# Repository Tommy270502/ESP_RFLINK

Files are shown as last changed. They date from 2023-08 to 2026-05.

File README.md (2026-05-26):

# Wireless Dev Bridge

Wireless Dev Bridge is a USB-C developer kit for ESP32-S3 and nRF24L01+ work. It gives one bench dongle a shared JSON command protocol over USB serial, HTTP, WebSocket, and BLE, plus a Python SDK, CLI, local web workbench, firmware browser dashboard, KiCad hardware source, and manufacturing outputs.

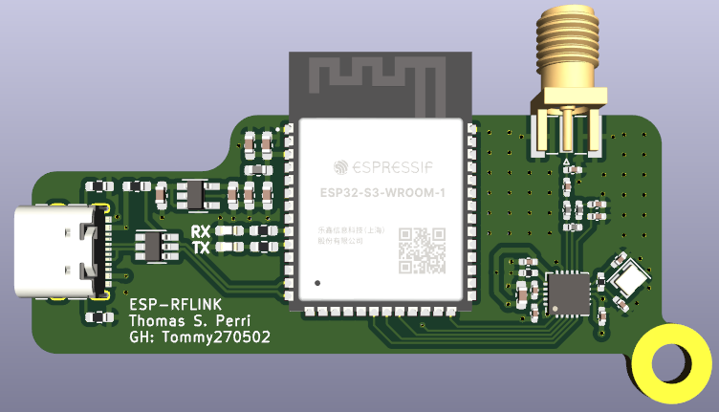
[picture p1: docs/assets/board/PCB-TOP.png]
Wireless Dev Bridge PCB top view


## Start Here

1. Read [Getting Started](docs/getting-started.md) for firmware build, SDK install, and first RF validation.
2. Use the local web workbench:

   ```bash
   pip install -r application/requirements.txt
   python application/main.py
   ```

3. Or install the SDK and CLI:

   ```bash
   cd sdk/python
   python -m pip install -e ".[all]"
   wdb discover
   wdb --serial COM5 identify
   wdb --serial COM5 diagnostics
   ```

4. For a two-dongle kit, flash one `node1` and one `node2`, then run:

   ```bash
   wdb pair-test --node1-serial COM5 --node2-serial COM6
   ```

## Product Surfaces

| Surface | Location | Description |
| --- | --- | --- |
| Firmware | `Firmware/ESP32_RFLINK` | PlatformIO ESP32-S3 firmware. |
| Local web workbench | `application` | FastAPI/browser host tool at `http://127.0.0.1:5173`. |
| SDK/CLI | `sdk/python` | Python SDK, CLI, examples, and hardware-free tests. |
| Firmware browser dashboard | `http://192.168.4.1` | Served by the dongle SoftAP. |
| Hardware | `hardware/kicad` | KiCad schematic and PCB source. |
| Manufacturing | `manufacturing/gerbers` | Current V1 Gerber/drill export. |

All transports share one command response envelope:

```json
{"ok":true,"cmd":"status","data":{},"error":null}
```

See [Project Overview](project-overview.md) for interfaces, validated bench workflows, and architecture detail.

## Protocol 1.1 Capabilities

- Shared command envelope over USB serial, HTTP, WebSocket, and BLE.
- Runtime RF config, address management, send/listen/flush, and bridge toggles.
- Settings persistence through NVS with `settings_get`, `settings_set`, `settings_save`, and `settings_reset`.
- Diagnostics and identify commands for support and physical device matching.
- Optional token auth for HTTP, WebSocket, and BLE command surfaces.
- Support report export from the CLI and local web workbench.

## Development Checks

```bash
cd Firmware/ESP32_RFLINK
pio run -e node1 -e node2

cd ../../sdk/python
python -m pytest

cd ../..
python -m py_compile application/main.py
python scripts/check_docs_links.py
```

## Documentation

- [Documentation Index](docs/documentation-index.md)
- [Project Overview](project-overview.md)
- [Getting Started](docs/getting-started.md)
- [First Run](docs/first-run.md)
- [API Reference](docs/api-reference.md)
- [Firmware Guide](docs/firmware.md)
- [Hardware Guide](docs/hardware.md)
- [Security Model](docs/security-model.md)
- [Troubleshooting](docs/troubleshooting.md)
- [Release Checklist](docs/release-checklist.md)
- [Local Web Workbench](application/desktop-workbench.md)
- [Python SDK](sdk/python/python-sdk-guide.md)

## V1 Boundaries

- nRF24 payloads are limited to 32 bytes.
- nRF24 address width is fixed at 5 bytes.
- RF configuration is runtime-only until saved with protocol 1.1 settings commands.
- HTTP, WebSocket, and BLE APIs are intended for trusted developer/lab networks.
- OTA, cloud connectivity, packet decoding, persistence, and mesh networking are out of scope for V1.

## License

Software is licensed under the MIT License; see [LICENSE](LICENSE). Hardware source and manufacturing outputs use the hardware license notice in [hardware/LICENSE.md](hardware/LICENSE.md).

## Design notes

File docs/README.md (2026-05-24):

# Documentation

Project documentation for Wireless Dev Bridge V1.

Start here:

- [Getting Started](getting-started.md): clone-to-hardware workflow.
- [API Reference](api-reference.md): shared JSON command protocol, HTTP routes, WebSocket events, and BLE UUIDs.
- [Firmware Guide](firmware.md): PlatformIO environments, modules, pin map, runtime defaults, and command examples.
- [Hardware Guide](hardware.md): KiCad source, board assets, manufacturing review notes, and firmware pin alignment.
- [Release Checklist](release-checklist.md): pre-release checks across firmware, host tools, RF validation, hardware, security, and support.

Host tool documentation lives with the tool:

- [Local Web Workbench](../application/README.md)
- [Python SDK](../sdk/python/README.md)

Validated V1 workflows:

- Two-dongle nRF24 ACK traffic over USB serial control.
- Runtime RF configuration from the local web workbench, CLI, SDK, HTTP, WebSocket, or BLE.
- Live packet monitoring through WebSocket and BLE notifications.
- Wi-Fi AP station count, BLE connection state, and RF TX/RX counters through `status`.

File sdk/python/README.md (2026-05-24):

# Wireless Dev Bridge Python SDK

Host-side SDK for the Wireless Dev Bridge firmware.

## Install

HTTP-only usage has no runtime dependencies:

```bash
# from the repository root
cd sdk/python
python -m pip install -e .
```

Install transport extras for USB serial, WebSocket, BLE, and MQTT examples:

```bash
python -m pip install -e ".[all]"
```

For tests only:

```bash
python -m pip install -e ".[test]"
```

## Quick Start

Minimal Wi-Fi connection, when your computer is connected to the dongle AP:

```python
from wireless_dev_bridge import BridgeError, WirelessDevBridge

dev = WirelessDevBridge.http("192.168.4.1", timeout=3.0)
try:
    print(dev.status())
    print(dev.rf_send_hex("1234", require_ack=False))
except BridgeError as exc:
    print(f"device request failed: {exc}")
finally:
    dev.close()
```

USB serial:

```python
from wireless_dev_bridge import WirelessDevBridge

dev = WirelessDevBridge.serial("COM5")
try:
    print(dev.self_test())
    dev.rf_send_bytes(b"hello", require_ack=True)
finally:
    dev.close()
```

BLE:

```python
from wireless_dev_bridge import WirelessDevBridge

dev = WirelessDevBridge.ble("WirelessDev-Node1")
try:
    dev.bridge(rf_to_ble=True)
    print(dev.protocol())
finally:
    dev.close()
```

## Getting Started By Workflow

Monitor RF packets from a dongle.
Use this when you need a live packet log during firmware bring-up or RF troubleshooting.

```bash
python examples/packet_monitor.py --ws 192.168.4.1 --count 10
python examples/packet_monitor.py --ble WirelessDev-Node1 --count 10
```

Expected output shape:

```text
2026-05-05T12:00:00+00:00 uptime_ms=12345 len=2 hex=1234
```

Bridge RF events to BLE.
Use this when a BLE host, phone app, or field tool should receive nRF24 packet events from the dongle.

```bash
wdb --ble WirelessDev-Node1 bridge rf-to-ble on
python examples/packet_monitor.py --ble WirelessDev-Node1 --count 10
```

Expected command response shape:

```json
{"ok":true,"cmd":"bridge","data":{"rf_to_ble":true},"error":null}
```

Bridge RF events to MQTT.
Use this for test benches, lab automation, or dashboards that already consume MQTT.

```bash
python -m pip install -e ".[mqtt]"
python examples/bridge_to_mqtt.py --ws 192.168.4.1 --broker localhost --topic-prefix lab/bridge1
```

Expected MQTT payload shape:

```json
{"type":"packet","source":"rf","data":{"len":2,"hex":"1234","uptime_ms":12345}}
```

Run a bench inventory/self-test.
Use this before a test run to verify firmware version, role, heap, radio health, and RF config.

```bash
python examples/device_inventory.py --device serial:COM5 --device serial:COM6
```

Expected output shape:

```text
SPEC                     OK  ROLE     FW         BLE                RADIO CH  RATE    RX       TX
serial:COM5              yes node1    0.1.0-v1   WirelessDev-Node1  yes   76  1mbps   NODE1    NODE2
```

Measure transport latency.
Use this to compare HTTP, USB serial, WebSocket, and BLE command round trips.

```bash
python examples/latency_benchmark.py --host 192.168.4.1 --count 50
python examples/latency_benchmark.py --ble WirelessDev-Node1 --count 50 --json
```

Expected output shape:

```text
http 192.168.4.1 ping
count=50 min=12.20ms avg=18.40ms p95=28.10ms max=31.80ms
```

Use the CLI for quick validation.
Use this when you want a fast smoke check without writing Python code.

```bash
wdb --serial COM5 self-test
wdb --host 192.168.4.1 status
wdb --ws 192.168.4.1 bridge rf-to-wifi on
wdb --ble WirelessDev-Node1 bridge rf-to-ble on
```

## Production Test

Run the bundled two-device production test over USB serial:

```bash
python examples/rf_ping.py --node1-serial COM8 --node2-serial COM11
```

This script:

- verifies each device role and radio health
- sets complementary RF addresses
- applies a known RF config
- flushes FIFOs and enables listening
- sends an ACK-required payload in each direction
- confirms the opposite device received the expected RF packet

For network-driven tests, pass the reachable HTTP host for each dongle. A dongle in SoftAP mode normally serves HTTP at `192.168.4.1`; if you are testing two SoftAP dongles, your host must connect to the correct AP or provide separate reachable routes for each device. USB serial is the simplest two-node path:

```bash
python examples/rf_ping.py --node1-serial COM8 --node2-serial COM11
```

## Examples

- `examples/packet_monitor.py`: stream RF packet events over WebSocket, BLE, or serial.
- `examples/bridge_to_mqtt.py`: publish RF packet events to MQTT. Requires `paho-mqtt` or `.[mqtt]`.
- `examples/ble_console.py`: run interactive or one-shot maintenance commands over BLE.
- `examples/latency_benchmark.py`: measure command or optional RF send latency.
- `examples/device_inventory.py`: run `self_test` and RF config reads across multiple devices.
- `examples/rf_ping.py`: two-device RF production test.
- `examples/production_demo.py`: flash two USB dongles, run two-way RF validation, and write a demo/factory JSON report.

All examples support `--help`.

## Two-Dongle Production Demo

Use this when presenting or validating a packaged two-dongle kit.

List connected serial ports:

```bash
python examples/production_demo.py --list-ports
```

Build, flash, test, and write a report:

```bash
python examples/production_demo.py --node1-serial COM5 --node2-serial COM6 --flash --operator TP --lot EVT1
```

If exactly two serial ports are visible and you want the script to choose them:

```bash
python examples/production_demo.py --auto-ports --flash
```

The report is written to `reports/` by default and includes role validation, radio health, RF config, ACK send checks, receive confirmation, elapsed time, and pass/fail status.

## CLI

```bash
wdb --host 192.168.4.1 status
wdb --host 192.168.4.1 rf-send 1234 --require-ack
wdb --serial COM5 self-test
wdb --serial COM5 rf-config --channel 76 --datarate 1mbps --power low
wdb --ws 192.168.4.1 bridge rf-to-wifi on
wdb --ble WirelessDev-Node1 bridge rf-to-ble on
wdb --ble WirelessDev-Node1 rf-send 1234 --require-ack
```

The legacy bridge form still controls RF-to-Wi-Fi:

```bash
wdb --ws 192.168.4.1 bridge on
wdb --ws 192.168.4.1 bridge off
```

The CLI prints the full device response JSON.

## Local Web Workbench

The repository also includes a local browser-hosted workbench at
`application/main.py`. It imports this SDK from a checkout and exposes the same
serial, HTTP, WebSocket, and BLE command paths as the CLI. It keeps open clients
per endpoint for two-dongle USB workflows and includes a Live Events tab for
WebSocket/BLE packet monitoring:

```bash
cd ../..
python -m pip install -r application/requirements.txt
python application/main.py
```

## BLE GATT Details

BLE uses newline-delimited JSON over a UART-style GATT service:

- Service UUID: `6e400001-b5a3-f393-e0a9-e50e24dcca9e`
- RX write UUID: `6e400002-b5a3-f393-e0a9-e50e24dcca9e`
- TX notify UUID: `6e400003-b5a3-f393-e0a9-e50e24dcca9e`

Subscribe to TX notifications before writing commands to RX. Notifications may contain partial JSON lines, so clients should buffer until `\n`.

## Tests

The SDK test suite does not require hardware:

```bash
# from the repository root
cd sdk/python
python -m pytest
```

## Product Applications

- nRF24 manufacturing tester: one dongle acts as the fixture controller while another or a known-good device acts as the golden peer.
- BLE-to-nRF24 bridge for mobile apps: a phone or tablet talks BLE to the ESP32-S3, then the dongle drives nRF24 test devices.
- RF regression harness: CI or bench scripts replay known packet patterns through the SDK.
- Classroom wireless lab tool: one USB-C dongle exposes serial, Wi-Fi, BLE, and 2.4 GHz RF workflows.
- Portable field diagnostic bridge: a laptop or BLE host inspects nearby nRF24-based nodes without a custom adapter.
- Interactive protocol workbench: combine WebSocket events with a browser UI for packet watch, send, and config changes.
- Sensor gateway prototype: nRF24 edge nodes report to the dongle while applications consume data through HTTP, WebSocket, or BLE.

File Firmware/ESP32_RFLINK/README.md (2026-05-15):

# Wireless Dev Bridge Firmware V1

Firmware for a USB-C multi-protocol wireless development interface based on an ESP32-S3-WROOM-1 and nRF24L01+.

For the full product launch package, start at the repository root `README.md`.

## Target

- Framework: PlatformIO + Arduino
- Board profile: `esp32-s3-devkitc-1`
- MCU: ESP32-S3-WROOM-1
- Flash target: 4 MB
- RF: nRF24L01+
- USB: native USB CDC serial

## Features

- Newline-delimited USB serial JSON command API
- nRF24L01+ send, receive, configure, listen control, FIFO flush, and address configuration
- Wi-Fi AP mode
- BLE GATT JSON command transport
- Browser dashboard at `http://192.168.4.1`
- WebSocket live RF packet stream on port `81`
- RF -> Wi-Fi/WebSocket bridge toggle
- RF -> BLE notification bridge toggle
- WebSocket -> RF send path through the same command protocol
- Production-oriented `self_test` command
- Python host SDK in repository root `sdk/python`

## Host SDK

A Python SDK is included for application and test development. HTTP mode works with the Python standard library. USB serial, WebSocket, and BLE modes use optional dependencies.

Install the SDK:

```bash
cd ../../sdk/python
python -m pip install -e .
```

Install all transport extras:

```bash
python -m pip install -e ".[all]"
```

Use the CLI over Wi-Fi:

```bash
wdb --host 192.168.4.1 status
wdb --host 192.168.4.1 rf-send 1234 --require-ack
```

Use the CLI over USB serial:

```bash
wdb --serial COM5 self-test
wdb --serial COM5 rf-config --channel 76 --datarate 1mbps --power low
```

Use the CLI over BLE:

```bash
wdb --ble WirelessDev-Node1 status
wdb --ble WirelessDev-Node1 bridge rf-to-ble on
wdb --ble WirelessDev-Node1 rf-send 1234 --require-ack
```

Use the desktop workbench from the repository root:

```bash
python application/main.py
```

The workbench is useful during firmware bring-up because it keeps serial
connections open per endpoint, prevents USB CDC reconnect resets while switching
between two dongles, exposes RF config/send/address/bridge controls, and can
stream RF packet events over WebSocket or BLE.

Use it from Python:

```python
from wireless_dev_bridge import WirelessDevBridge

dev = WirelessDevBridge.serial("COM5")
print(dev.status())
dev.rf_send_bytes(b"hello", require_ack=True)
```

BLE from Python:

```python
from wireless_dev_bridge import WirelessDevBridge

dev = WirelessDevBridge.ble("WirelessDev-Node1")
dev.bridge(rf_to_ble=True)
print(dev.protocol())
```

Run the bundled two-device production test:

```bash
cd ../../sdk/python
python examples/rf_ping.py --node1-serial COM8 --node2-serial COM11
```

Run the polished two-dongle production demo with flashing and a JSON report:

```bash
python examples/production_demo.py --node1-serial COM8 --node2-serial COM11 --flash
```

Additional launch examples are included in repository root `sdk/python/examples`:

- `packet_monitor.py`: stream RF packet events over WebSocket, BLE, or serial.
- `bridge_to_mqtt.py`: publish RF packet events to MQTT for lab automation. Requires `paho-mqtt` or `.[mqtt]`.
- `ble_console.py`: run interactive or one-shot maintenance commands over BLE.
- `latency_benchmark.py`: measure command or optional RF send latency.
- `device_inventory.py`: inventory firmware, role, heap, radio health, and RF config across devices.
- `production_demo.py`: build, flash, validate, and report a two-dongle kit.

## Getting Started By Workflow

Monitor RF packets from a dongle when bringing up RF firmware or debugging packet flow:

```bash
cd ../../sdk/python
python examples/packet_monitor.py --ws 192.168.4.1 --count 10
```

Expected output shape:

```text
2026-05-05T12:00:00+00:00 uptime_ms=12345 len=2 hex=1234
```

The desktop workbench **Live Events** tab provides the same WebSocket/BLE packet
visibility while USB serial remains available for command control.

Bridge RF events to BLE when a BLE host or mobile app should receive nRF24 packet events:

```bash
wdb --ble WirelessDev-Node1 bridge rf-to-ble on
python examples/packet_monitor.py --ble WirelessDev-Node1 --count 10
```

Bridge RF events to MQTT for bench automation or dashboards:

```bash
python -m pip install -e ".[mqtt]"
python examples/bridge_to_mqtt.py --ws 192.168.4.1 --broker localhost --topic-prefix lab/bridge1
```

Run a bench inventory/self-test before test execution:

```bash
python examples/device_inventory.py --device serial:COM5 --device serial:COM6
```

Measure transport latency across HTTP, USB serial, WebSocket, or BLE:

```bash
python examples/latency_benchmark.py --host 192.168.4.1 --count 50
python examples/latency_benchmark.py --ble WirelessDev-Node1 --count 50 --json
```

Use the CLI for quick validation:

```bash
wdb --serial COM5 self-test
wdb --host 192.168.4.1 status
wdb --ws 192.168.4.1 bridge rf-to-wifi on
wdb --ble WirelessDev-Node1 bridge rf-to-ble on
```

Expected command responses use the standard JSON shape described below with `ok`, `cmd`, `data`, and `error`.

## Product Applications

- nRF24 manufacturing tester: one dongle acts as the fixture controller while another or a known-good device acts as the golden peer.
- BLE-to-nRF24 bridge for mobile apps: a phone or tablet talks BLE to the ESP32-S3, then the dongle drives nRF24 test devices.
- RF regression harness: CI or bench scripts replay known packet patterns through the SDK.
- Classroom wireless lab tool: one USB-C dongle exposes serial, Wi-Fi, BLE, and 2.4 GHz RF workflows.
- Portable field diagnostic bridge: a laptop or BLE host inspects nearby nRF24-based nodes without a custom adapter.
- Interactive protocol workbench: combine WebSocket events with a browser UI for packet watch, send, and config changes.
- Sensor gateway prototype: nRF24 edge nodes report to the dongle while applications consume data through HTTP, WebSocket, or BLE.

## Build And Upload

1. Open this folder in PlatformIO.
2. Review hardware values in `include/Config.h`.
3. Build the default environment. The default is `node1`:

```bash
pio run
```

4. Upload the default environment:

```bash
pio run --target upload
```

If the device was previously flashed with an 8 MB image or shows core dump CRC warnings, erase once before uploading:

```bash
pio run --target erase
pio run --target upload
```

BLE support requires a larger app partition than the Arduino default OTA layout provides on 4 MB flash. This firmware uses `no_ota.csv`, giving one larger app slot and no OTA slot.

5. Monitor serial:

```bash
pio device monitor -b 115200
```

## Node-Specific Builds

Two PlatformIO environments are provided for RF pair testing:

- `node1`: RX `NODE1`, TX `NODE2`, Wi-Fi AP `WirelessDev-Node1`
- `node2`: RX `NODE2`, TX `NODE1`, Wi-Fi AP `WirelessDev-Node2`

Build both:

```bash
pio run -e node1 -e node2
```

Upload node 1:

```bash
pio run -e node1 --target upload
```

Upload node 2:

```bash
pio run -e node2 --target upload
```

If both boards are connected, list ports first:

```bash
pio device list
```

Then upload to a specific port:

```bash
pio run -e node1 --target upload --upload-port COM5
pio run -e node2 --target upload --upload-port COM6
```

Monitor a specific port:

```bash
pio device monitor -p COM5 -b 115200
pio device monitor -p COM6 -b 115200
```

## Pin Configuration

Edit `include/Config.h` for the final PCB:

- `PIN_NRF_CE`
- `PIN_NRF_CSN`
- `PIN_NRF_SCK`
- `PIN_NRF_MOSI`
- `PIN_NRF_MISO`
- `PIN_LED_Rx`
- `PIN_LED_Tx`
- `PIN_LED`

The default nRF24 address width is 5 bytes. The fallback generic defaults are printable developer values:

- RX: `NODE1`
- TX: `NODE2`

For paired testing, prefer the `node1` and `node2` PlatformIO environments above so the addresses are complementary at build time.

## Wi-Fi AP

- SSID: `WirelessDev-Bridge`
- Node 1 SSID: `WirelessDev-Node1`
- Node 2 SSID: `WirelessDev-Node2`
- Password: `12345678`
- Dashboard: `http://192.168.4.1`
- WebSocket: `ws://192.168.4.1:81/`

## BLE GATT

The firmware advertises as the node-specific BLE name:

- Node 1: `WirelessDev-Node1`
- Node 2: `WirelessDev-Node2`

BLE uses a UART-style GATT profile with newline-delimited JSON framing:

- Service UUID: `6e400001-b5a3-f393-e0a9-e50e24dcca9e`
- RX write UUID: `6e400002-b5a3-f393-e0a9-e50e24dcca9e`
- TX notify UUID: `6e400003-b5a3-f393-e0a9-e50e24dcca9e`

Write command JSON to the RX characteristic. Subscribe to TX notifications for command responses and RF packet events. Responses are newline-terminated and may be split across multiple BLE notifications.

## Command Response Format

All command responses use this shape:

```json
{
  "ok": true,
  "cmd": "status",
  "data": {},
  "error": null
}
```

Errors use a code and message:

```json
{
  "ok": false,
  "cmd": "rf_send",
  "data": {},
  "error": {
    "code": "payload_too_large",
    "message": "payload must be 32 bytes or less"
  }
}
```

## Serial Commands

Each command is one newline-delimited JSON object.

```json
{"cmd":"ping"}
```

```json
{"cmd":"status"}
```

```json
{"cmd":"self_test"}
```

```json
{"cmd":"rf_get_config"}
```

```json
{"cmd":"rf_config","channel":76,"datarate":"1mbps","power":"low"}
```

```json
{"cmd":"rf_config","auto_ack":true}
```

```json
{"cmd":"rf_send","hex":"68656C6C6F"}
```

By default `rf_send` transmits a no-ACK payload. Use `require_ack` when a peer radio is expected to acknowledge the packet:

```json
{"cmd":"rf_send","hex":"68656C6C6F","require_ack":true}
```

```json
{"cmd":"rf_start_listen"}
```

```json
{"cmd":"rf_stop_listen"}
```

```json
{"cmd":"rf_flush_rx"}
```

```json
{"cmd":"rf_flush_tx"}
```

Set a printable 5-byte address:

```json
{"cmd":"rf_set_address","pipe":"rx","address":"NODE1","format":"ascii"}
```

Set a 5-byte hex address:

```json
{"cmd":"rf_set_address","pipe":"tx","address":"4E4F444532","format":"hex"}
```

Set both addresses:

```json
{"cmd":"rf_set_address","rx":"NODE1","tx":"NODE2","format":"ascii"}
```

Bridge toggle:

```json
{"cmd":"bridge","rf_to_wifi":true}
```

Bridge RF packets to BLE notifications:

```json
{"cmd":"bridge","rf_to_ble":true}
```

## HTTP API Examples

Status:

```http
GET /api/status
```

Self-test:

```http
GET /api/self_test
```

Generic command endpoint:

```http
POST /api/command
Content-Type: application/json

{"cmd":"rf_get_config"}
```

RF config:

```http
POST /api/rf/config
Content-Type: application/json

{"channel":76,"datarate":"1mbps","power":"low"}
```

RF send:

```http
POST /api/rf/send
Content-Type: application/json

{"hex":"68656C6C6F"}
```

Bridge toggle:

```http
POST /api/bridge
Content-Type: application/json

{"rf_to_wifi":true}
```

Additional routes:

- `GET /api/rf/config`
- `POST /api/rf/listen/start`
- `POST /api/rf/listen/stop`
- `POST /api/rf/flush_rx`
- `POST /api/rf/flush_tx`

## WebSocket Messages

Connect to:

```text
ws://192.168.4.1:81/
```

Incoming RF packet event:

```json
{
  "type": "packet",
  "source": "rf",
  "data": {
    "len": 5,
    "hex": "68656C6C6F",
    "uptime_ms": 12345
  }
}
```

Status event:

```json
{
  "type": "status",
  "data": {
    "fw": "0.1.0-v1",
    "uptime_ms": 12345,
    "radio": {},
    "wifi": {},
    "bridge": {},
    "stats": {}
  }
}
```

You can send command JSON over WebSocket too:

```json
{"cmd":"rf_send","hex":"68656C6C6F"}
```

## BLE Messages

BLE uses the same command response format as USB serial, HTTP, and WebSocket. Packet events use the same event object:

```json
{"type":"packet","source":"rf","data":{"len":2,"hex":"1234","uptime_ms":12345}}
```

## Boot Log

On startup the firmware emits a serial boot JSON message:

```json
{
  "type": "boot",
  "ok": true,
  "cmd": "boot",
  "data": {
    "product": "WirelessDevBridge",
    "fw": "0.1.0-v1",
    "uptime_ms": 1000,
    "radio_initialized": true,
    "radio_chip_connected": true,
    "ap_ssid": "WirelessDev-Bridge",
    "ap_ip": "192.168.4.1",
    "ble_enabled": true,
    "ble_name": "WirelessDev-Node1"
  },
  "error": null
}
```

## Known Limitations

- nRF24 payloads are limited to 32 bytes.
- nRF24 addresses are fixed at 5 bytes in this V1 firmware.
- Wi-Fi AP has no authentication beyond the shared AP password.
- HTTP, WebSocket, and BLE APIs are not authenticated.
- No OTA, cloud, packet decoding, mesh networking, or persistence yet.
- RF settings are runtime-only and reset after reboot.

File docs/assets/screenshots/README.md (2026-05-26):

# Screenshot Checklist

Add current screenshots for each tagged product release:

- Local web workbench device overview.
- Local web workbench two-dongle validation or support report export.
- Firmware browser dashboard device/RF/log view.
- CLI `wdb report` summary.

Use screenshots in release notes and the project README once the visual state is validated for the release.

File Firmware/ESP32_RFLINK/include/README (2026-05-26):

# Firmware Headers

This folder contains project headers for the Wireless Dev Bridge firmware.

Key files:

- `Config.h`: firmware constants, pin map, role-specific defaults, BLE UUIDs, RF limits, and product version strings.
- `CommandService.h`: shared JSON command handler used by serial, HTTP, WebSocket, and BLE transports.
- `RadioService.h`: nRF24L01+ configuration, TX/RX, listen state, FIFO, and address operations.
- `WebService.h` and `WebUi.h`: SoftAP HTTP API, firmware browser dashboard, and WebSocket event stream.
- `BleService.h`: BLE UART-style command and notification transport.
- `BridgeService.h`: RF packet forwarding state for Wi-Fi/WebSocket and BLE.
- `AppState.h`: runtime RF config, bridge config, and counters.

Any change to command names, response shape, pin mapping, RF limits, BLE UUIDs,
or runtime defaults should be reflected in the root docs and API reference.

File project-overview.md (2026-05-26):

# Wireless Dev Bridge

Wireless Dev Bridge PCB top view

Wireless Dev Bridge is a compact USB-C developer dongle for engineers who need one bench interface for Wi-Fi, BLE, and nRF24L01-based 2.4 GHz RF systems. It combines an ESP32-S3, native USB CDC serial, a firmware browser dashboard, BLE GATT, WebSocket streaming, and an nRF24L01+ radio path behind one JSON command protocol.

This repository is organized as a V1 external developer launch package: firmware, host tools, hardware source, board renders, and manufacturing outputs are all included.

## What You Can Do

- Bridge nRF24 packets to USB serial, Wi-Fi/WebSocket, or BLE notifications.
- Send and receive 32-byte nRF24 payloads from scripts, the CLI, the local web workbench, or the firmware browser dashboard.
- Configure RF channel, datarate, power, auto-ACK, listen state, and 5-byte pipe addresses.
- Watch live RF packet events over WebSocket or BLE while controlling devices over USB serial.
- Run two-dongle RF ping and production-style self-test workflows.
- Use the Python SDK, CLI, or local web workbench without writing embedded code.

## Quick Start

Build and flash firmware:

```bash
cd Firmware/ESP32_RFLINK
pio run -e node1
pio run -e node1 --target upload
```

Install the Python SDK:

```bash
cd sdk/python
python -m pip install -e ".[all]"
```

Validate a dongle over USB serial:

```bash
wdb --serial COM5 self-test
wdb --serial COM5 status
```

Launch the local web workbench (`http://127.0.0.1:5173`):

```bash
# from the repository root
python application/main.py
```

Use the local web workbench to configure both node roles, send ACK-required RF packets in both directions, watch counters, and stream RF packet events over WebSocket or BLE.

Run the two-dongle production demo with flashing and a JSON report:

```bash
python examples/production_demo.py --node1-serial COM5 --node2-serial COM6 --flash
```

Use Wi-Fi after connecting your computer to the dongle AP:

```bash
wdb --host 192.168.4.1 status
```

Open the firmware browser dashboard at:

```text
http://192.168.4.1
```

## Repository Layout

| Path | Purpose |
| --- | --- |
| `Firmware/ESP32_RFLINK` | PlatformIO firmware for the ESP32-S3 dongle. |
| `application` | Local FastAPI/browser workbench for the shared command protocol. |
| `sdk/python` | Python SDK, CLI, examples, and hardware-free tests. |
| `hardware/kicad` | KiCad schematic and PCB source. |
| `manufacturing/gerbers` | Current V1 Gerber/drill export. |
| `docs` | Product, API, hardware, and launch documentation. |
| `docs/assets/board` | Board images used by the docs. |

## Developer Interfaces

| Interface | Default endpoint | Use case |
| --- | --- | --- |
| USB CDC serial | 115200 baud JSONL | Reliable bench automation and flashing-adjacent validation. |
| HTTP JSON | `http://192.168.4.1` | Simple host scripts and firmware browser dashboard. |
| WebSocket JSON | `ws://192.168.4.1:81/` | Live packet monitor and RF event streaming. |
| BLE GATT | `WirelessDev-Node1` or `WirelessDev-Node2` | Mobile, field, and BLE-host workflows. |

The local web workbench and Python SDK can use these same transports from the host side.

All transports share the same command response envelope:

```json
{"ok":true,"cmd":"status","data":{},"error":null}
```

## Validated Bench Workflow

For a two-dongle RF bench, flash one dongle as `node1` and one as `node2`. Keep their RF channel, datarate, and auto-ACK settings matched. The default addresses are complementary:

| Role | RX address | TX address |
| --- | --- | --- |
| `node1` | `NODE1` | `NODE2` |
| `node2` | `NODE2` | `NODE1` |

In the local web workbench, use USB serial for reliable command control. The app keeps open connections per endpoint so switching between COM ports does not reset the boards. `status` counters should show `rf_tx` increasing on the sender and `rf_rx` increasing on the peer.

To prove wireless event streaming, use the **Live Events** tab:

- WebSocket: connect the PC to a dongle AP, stream from `192.168.4.1`, and send RF from the peer.
- BLE: stream from `WirelessDev-Node1` or `WirelessDev-Node2`, then send RF from the peer.

## Documentation

- [Documentation Index](docs/documentation-index.md)
- [Getting Started](docs/getting-started.md)
- [API Reference](docs/api-reference.md)
- [Firmware Guide](docs/firmware.md)
- [Hardware Guide](docs/hardware.md)
- [Release Checklist](docs/release-checklist.md)
- [Local Web Workbench](application/desktop-workbench.md)
- [Python SDK](sdk/python/python-sdk-guide.md)

## V1 Boundaries

- nRF24 payloads are limited to 32 bytes.
- nRF24 address width is fixed at 5 bytes.
- RF configuration is runtime-only until saved with protocol `1.1` settings commands.
- HTTP, WebSocket, and BLE APIs are intended for trusted developer/lab networks.
- OTA, cloud connectivity, packet decoding, persistence, and mesh networking are out of scope for V1.

## License

Software is licensed under the MIT License. Hardware source and manufacturing outputs carry the hardware license notice in `hardware/LICENSE.md`.

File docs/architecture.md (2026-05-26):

# Architecture

System architecture for Wireless Dev Bridge V1.

## Host Tools And Transports

```mermaid
graph LR
    subgraph Host
        CLI["Python CLI<br/>(wdb)"]
        SDK["Python SDK<br/>(WirelessDevBridge)"]
        WB["Local Web Workbench<br/>(FastAPI + browser)"]
        Script["User Scripts"]
    end

    subgraph Dongle["ESP32-S3 Dongle"]
        Serial["USB CDC Serial"]
        HTTP["HTTP API"]
        WS["WebSocket"]
        BLE["BLE GATT"]
        CMD["CommandService"]
    end

    CLI --> SDK
    WB --> SDK
    Script --> SDK

    SDK -->|JSONL| Serial
    SDK -->|JSON| HTTP
    SDK -->|JSON| WS
    SDK -->|JSON| BLE

    Serial --> CMD
    HTTP --> CMD
    WS --> CMD
    BLE --> CMD
```

## Firmware Module Structure

```mermaid
graph TD
    main["main.cpp<br/>setup / loop"]

    main --> AppState["AppState<br/>Shared runtime state"]
    main --> CMD["CommandService<br/>JSON command dispatcher"]
    main --> Radio["RadioService<br/>nRF24L01+ driver"]
    main --> Web["WebService<br/>SoftAP, HTTP, WebSocket"]
    main --> BLE_S["BleService<br/>BLE UART transport"]
    main --> Bridge["BridgeService<br/>RF-to-WiFi/BLE forwarding"]
    main --> Settings["SettingsService<br/>NVS persistence"]
    main --> WebUi["WebUi<br/>Firmware browser dashboard"]

    CMD --> Radio
    CMD --> Settings
    CMD --> Bridge
    CMD --> AppState

    Bridge --> Web
    Bridge --> BLE_S

    Radio -->|RX packets| Bridge
```

## Command Layer

All transports share one command request/response envelope:

```
Request:  {"cmd":"<name>", ...params}
Response: {"ok":true|false, "cmd":"<name>", "data":{...}, "error":null|"..."}
```

```mermaid
graph LR
    subgraph Transports
        S["USB Serial"]
        H["HTTP POST"]
        W["WebSocket"]
        B["BLE Write"]
    end

    subgraph CommandService
        Parse["Parse JSON"]
        Dispatch["Dispatch by cmd"]
        Reply["Build response"]
    end

    subgraph Services
        RF["RF Config / Send / Listen"]
        Addr["Address Management"]
        Br["Bridge Toggles"]
        Set["Settings CRUD"]
        Diag["Diagnostics / Identify"]
        Auth["Optional Token Auth"]
    end

    S --> Parse
    H --> Parse
    W --> Parse
    B --> Parse

    Parse --> Auth
    Auth --> Dispatch

    Dispatch --> RF
    Dispatch --> Addr
    Dispatch --> Br
    Dispatch --> Set
    Dispatch --> Diag

    RF --> Reply
    Addr --> Reply
    Br --> Reply
    Set --> Reply
    Diag --> Reply
```

## RF And Settings Services

```mermaid
graph TD
    subgraph Runtime
        RFConfig["RF Config<br/>channel, datarate, power, auto_ack"]
        Addresses["Pipe Addresses<br/>5-byte RX/TX"]
        BridgeState["Bridge State<br/>rf_to_wifi, rf_to_ble"]
        ListenState["Listen State<br/>start/stop"]
    end

    subgraph Persistence["NVS Persistence"]
        Save["settings_save"]
        Load["settings_get"]
        Reset["settings_reset"]
    end

    RFConfig -->|"settings_set"| Save
    Addresses -->|"settings_set"| Save
    BridgeState -->|"settings_set"| Save
    Save -->|reboot| Load
    Load --> RFConfig
    Load --> Addresses
    Load --> BridgeState
    Reset -->|"factory defaults"| Load
```

## Hardware Block Diagram

```mermaid
graph LR
    USB["USB-C<br/>Data + Power"] --> ESP["ESP32-S3<br/>Wi-Fi, BLE, USB CDC"]
    ESP -->|SPI| NRF["nRF24L01+<br/>2.4 GHz RF"]
    ESP --> LED["Status LED"]
    ESP --> Flash["4 MB Flash<br/>NVS + App"]
    NRF --> ANT["PCB Antenna<br/>or u.FL"]
```

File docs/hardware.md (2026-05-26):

# Hardware Guide

The hardware source is a KiCad project for the ESP32-S3 and nRF24L01+ USB-C developer dongle.

## Board Assets

Top view:

PCB top view

Bottom view:

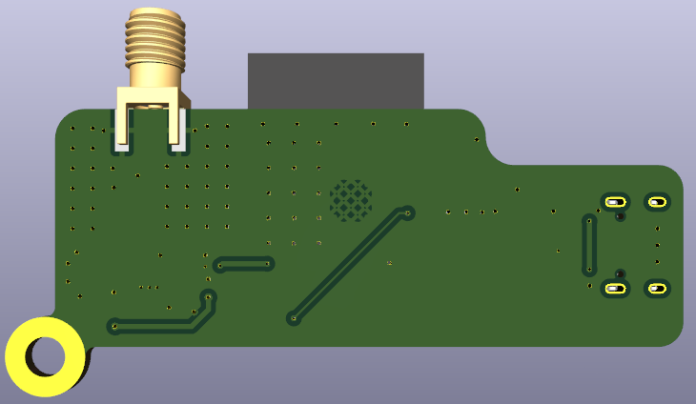
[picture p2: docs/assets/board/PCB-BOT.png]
PCB bottom view


## Paths

| Path | Purpose |
| --- | --- |
| `hardware/kicad/ESPxRF.kicad_pro` | KiCad project entry point. |
| `hardware/kicad/ESPxRF.kicad_sch` | Schematic source. |
| `hardware/kicad/ESPxRF.kicad_pcb` | PCB layout source. |
| `hardware/BOM.md` | BOM release checklist and sourcing notes. |
| `hardware/ASSEMBLY.md` | Assembly and bring-up notes. |
| `hardware/BOARD_REVISION.md` | Board revision notes. |
| `hardware/PINOUT.md` | Pinout card for firmware/hardware alignment. |
| `manufacturing/gerbers` | Current Gerber and drill export. |

## Opening In KiCad

Open:

```text
hardware/kicad/ESPxRF.kicad_pro
```

The tracked KiCad files should not depend on user-local absolute paths. Standard component 3D models reference KiCad library variables where available. No project-local 3D model bundle is currently tracked in this repository.

## Manufacturing Outputs

The current generated manufacturing files are in:

```text
manufacturing/gerbers
```

Before ordering boards for a public release:

- Re-run KiCad DRC/ERC in the KiCad version used for release.
- Inspect copper, solder mask, paste, silkscreen, edge cuts, and drills in a Gerber viewer.
- Confirm stackup, board thickness, copper weight, impedance expectations, and RF connector footprint requirements with the fab.
- Generate a fresh fab package from `hardware/kicad/ESPxRF.kicad_pcb` if the layout changes.

## Firmware Pin Alignment

The firmware pin map is kept in:

```text
Firmware/ESP32_RFLINK/include/Config.h
```

Any PCB routing change that affects the nRF24 SPI bus, CE/CSN, or LEDs must be reflected there before releasing firmware.

## Verification Status

**Verified through design review:**

- Schematic captures ESP32-S3, nRF24L01+, USB-C, and status LED connections.
- PCB layout generated Gerber/drill output in `manufacturing/gerbers`.
- Firmware pin map in `Config.h` aligns with schematic net names.
- BOM components are sourced from standard distributors.

**Requires hardware validation:**

- PCB fabrication and assembly from the current Gerber export.
- nRF24L01+ SPI communication on the production board.
- USB-C enumeration and CDC serial on the production board.
- RF range and reliability testing with production antennas.
- Thermal behavior under sustained TX/RX workloads.
- ESD and EMC compliance if applicable to the deployment environment.

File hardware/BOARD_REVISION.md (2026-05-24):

# Board Revision Notes

## V1

- ESP32-S3-WROOM-1 target.
- nRF24L01+ RF path.
- Native USB CDC serial.
- Firmware pin map is documented in `docs/firmware.md` and defined in `Firmware/ESP32_RFLINK/include/Config.h`.

Any PCB change that affects USB, power, nRF24 SPI, CE/CSN, IRQ, LEDs, or the RF path must update firmware config, board images, Gerber export, and release notes in the same release.

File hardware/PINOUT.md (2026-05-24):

# Pinout Card

| Signal | GPIO |
| --- | --- |
| nRF24 CE | 45 |
| nRF24 CSN | 15 |
| nRF24 SCK | 14 |
| nRF24 MOSI | 13 |
| nRF24 MISO | 12 |
| nRF24 IRQ | 18 |
| RX LED | 16 |
| TX LED | 17 |

The authoritative firmware values live in `Firmware/ESP32_RFLINK/include/Config.h`.

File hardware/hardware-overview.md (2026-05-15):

# Hardware

KiCad hardware source for Wireless Dev Bridge V1.

Open the KiCad project at:

```text
hardware/kicad/ESPxRF.kicad_pro
```

Manufacturing outputs are kept separately in:

```text
manufacturing/gerbers
```

See [Hardware Guide](../docs/hardware.md) for board assets, KiCad notes, manufacturing review steps, and firmware pin alignment.

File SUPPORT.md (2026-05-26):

# Support

For V1 developer support, include:

- Firmware version from `status` or `self_test`.
- Host tool and transport used: CLI, SDK, local web workbench, firmware browser dashboard; USB serial, HTTP, WebSocket, or BLE.
- Host OS and Python version when using the SDK.
- Hardware role: `node1`, `node2`, or custom build flags.
- Relevant command JSON and full response JSON.
- RF config: channel, datarate, power, auto-ACK, RX address, and TX address.

For hardware issues, include clear photos of the board, power symptoms, USB enumeration behavior, and whether the KiCad/Gerber release was modified.

Preferred report command:

```bash
wdb --serial <port> report --output wireless-dev-bridge-report.json
```

The local web workbench can export the same support report from the selected connection.

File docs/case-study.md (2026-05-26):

# Case Study: Wireless Dev Bridge

## Problem

Engineers working with nRF24L01+ radios need a reliable way to send, receive, and monitor 2.4 GHz RF packets from a development host. Existing approaches require custom firmware per project, manual serial protocol parsing, and no standard tooling for RF pair testing or production validation.

## Constraints

- Must work from a single USB-C dongle with no external power or adapters.
- Must expose RF operations through transports that scripts, browsers, mobile apps, and BLE hosts can all reach.
- Must use one shared command protocol across all transports to avoid per-transport divergence.
- Must support two-dongle RF pair testing for production validation workflows.
- Must include hardware source and manufacturing outputs for reproducibility.
- V1 scope: no OTA, cloud, packet decoding, mesh, or production security hardening.

## Architecture Decisions

**ESP32-S3 as the host MCU.** Native USB CDC serial eliminates the need for an external FTDI or CP2102. Wi-Fi AP mode, BLE GATT, and SPI for the nRF24L01+ are all available on one chip.

**JSON command protocol.** One command/response envelope (`ok`, `cmd`, `data`, `error`) shared across USB serial (JSONL), HTTP, WebSocket, and BLE. This lets the same SDK client, CLI, and workbench code work over any transport without translation layers.

**FastAPI local web workbench.** A browser-based host tool at `http://127.0.0.1:5173` backed by FastAPI and the Python SDK. Provides RF config, packet send, address presets, bridge toggles, live events (via SSE), and command/event logs. Keeps SDK client connections open per `(transport, endpoint, timeout)` to prevent USB CDC reconnect resets when switching between two dongles.

**Firmware browser dashboard.** A minimal dashboard served by the ESP32-S3 SoftAP at `http://192.168.4.1`. Provides status, RF controls, and event visibility when a host tool is not available.

**Python SDK with optional transports.** HTTP works with the standard library. Serial, WebSocket, and BLE are optional dependencies. The CLI wraps the SDK for terminal workflows. Hardware-free tests validate command mapping and report formatting without connected dongles.

**NVS settings persistence.** Protocol 1.1 added `settings_save` and `settings_reset` so RF config, addresses, bridge state, device names, and optional auth survive reboots.

## Implementation Summary

| Layer | Technology | Key files |
| --- | --- | --- |
| Firmware | PlatformIO + Arduino, ESP32-S3 | `Firmware/ESP32_RFLINK/src/` |
| Command dispatch | `CommandService.cpp` | Parses JSON, dispatches to RF/settings/bridge/diagnostics services |
| RF driver | `RadioService.cpp` + RF24 library | nRF24L01+ config, TX/RX, listen, flush, address |
| Settings | `SettingsService.cpp` + ESP-IDF NVS | Persist/restore RF, bridge, device, security settings |
| Web | `WebService.cpp` + `WebUi.cpp` | SoftAP, HTTP API, firmware browser dashboard, WebSocket events |
| BLE | `BleService.cpp` | BLE GATT UART-style command/event transport |
| Bridge | `BridgeService.cpp` | RF packet forwarding to WebSocket and BLE |
| SDK | Python (`wireless_dev_bridge/`) | Serial, HTTP, WebSocket, BLE client; CLI; examples |
| Workbench | Python + FastAPI (`application/`) | Local browser UI backed by SDK |
| Hardware | KiCad (`hardware/kicad/`) | Schematic and PCB source |

## Validation Evidence

The following checks are automated in CI or run locally:

- **SDK tests**: 25 hardware-free tests covering command mapping, CLI bridge, and examples (`sdk/python/tests/`).
- **Application compile**: `python -m py_compile application/main.py` verifies the FastAPI backend is syntactically valid.
- **Docs link check**: `python scripts/check_docs_links.py` verifies all Markdown cross-references resolve.
- **Conflict-marker check**: `rg "^(<<<<<<<|=======|>>>>>>>)" .` ensures no merge artifacts remain.
- **Firmware build**: `pio run -e node1 -e node2` builds both node roles (requires PlatformIO).

## Unverified Items

The following require hardware that may not be available in every environment:

- USB serial command round-trip with physical dongles.
- Two-dongle RF ACK traffic and `pair-test` validation.
- WebSocket and BLE live packet event streaming.
- NVS settings persistence across reboot cycles.
- Optional token auth enforcement over HTTP, WebSocket, and BLE.
- nRF24L01+ radio initialization on the production PCB.
- Firmware browser dashboard rendering and control on the SoftAP.

These items are documented in the [Beta Validation](beta-validation.md) matrix and [Release Checklist](release-checklist.md).

## Business Value

This repository demonstrates:

- **Full-stack embedded product delivery**: firmware, host tools, hardware source, manufacturing outputs, and documentation in one package.
- **Multi-transport architecture**: one command protocol serving four transports without code duplication.
- **Developer experience focus**: SDK, CLI, browser workbench, and examples that work without writing embedded code.
- **Production readiness awareness**: validation checklists, support report infrastructure, and honest documentation of what has and has not been hardware-validated.
- **Reproducible hardware**: KiCad source and Gerber/drill exports included for board fabrication.

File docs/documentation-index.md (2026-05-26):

# Documentation

Project documentation for Wireless Dev Bridge V1.

## Getting Started

- [Getting Started](getting-started.md): clone-to-hardware workflow.
- [First Run](first-run.md): product path for identifying, validating, saving settings, and exporting reports.

## Architecture And Protocol

- [Architecture](architecture.md): Mermaid diagrams for host tools, transports, command layer, services, and hardware.
- [API Reference](api-reference.md): shared JSON command protocol, HTTP routes, WebSocket events, and BLE UUIDs.
- [Firmware Guide](firmware.md): PlatformIO environments, modules, pin map, runtime defaults, and command examples.
- [Security Model](security-model.md): trusted-bench defaults and optional token auth.

## Host Tools

- [Local Web Workbench](../application/desktop-workbench.md): FastAPI/browser workbench at `http://127.0.0.1:5173`.
- [Python SDK](../sdk/python/python-sdk-guide.md): SDK, CLI, examples, and hardware-free tests.

## Hardware And Manufacturing

- [Hardware Guide](hardware.md): KiCad source, board assets, manufacturing review notes, and firmware pin alignment.
- [Manufacturing Guide](../manufacturing/manufacturing-guide.md): Gerber/drill export and production notes.
- [Hardware License](../hardware/LICENSE.md): hardware license notice.

## Operations

- [Troubleshooting](troubleshooting.md): support report, serial, RF, Wi-Fi, BLE, and reset guidance.
- [Beta Validation](beta-validation.md): cross-platform and hardware-in-loop validation matrix.
- [Release Checklist](release-checklist.md): pre-release checks across firmware, host tools, RF validation, hardware, security, and support.

## Case Study

- [Case Study](case-study.md): problem, constraints, architecture, implementation, and validation evidence.

## Validated V1 Workflows

- Two-dongle nRF24 ACK traffic over USB serial control.
- Runtime RF configuration from the local web workbench, CLI, SDK, HTTP, WebSocket, or BLE.
- Live packet monitoring through WebSocket and BLE notifications.
- Wi-Fi AP station count, BLE connection state, and RF TX/RX counters through `status`.
- Protocol 1.1 settings persistence, diagnostics, identify, optional auth, and support report export.

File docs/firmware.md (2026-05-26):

# Firmware Guide

The firmware lives in `Firmware/ESP32_RFLINK` and uses PlatformIO with the Arduino framework.

## Target

- MCU: ESP32-S3-WROOM-1
- Board profile: `esp32-s3-devkitc-1`
- Flash: 4 MB
- Partition table: `no_ota.csv`
- USB: native USB CDC serial
- RF: nRF24L01+

BLE support requires a larger application partition than the default Arduino OTA layout provides on 4 MB flash, so V1 uses a single no-OTA app slot.

## Build Environments

`node1` is the default environment:

```bash
cd Firmware/ESP32_RFLINK
pio run
```

Two node-specific environments are provided for paired RF validation:

| Environment | RX address | TX address | AP/BLE name |
| --- | --- | --- | --- |
| `node1` | `NODE1` | `NODE2` | `WirelessDev-Node1` |
| `node2` | `NODE2` | `NODE1` | `WirelessDev-Node2` |

Build both:

```bash
pio run -e node1 -e node2
```

## Source Modules

| Module | Responsibility |
| --- | --- |
| `main.cpp` | Boot sequence, service polling, boot JSON message. |
| `Config.h` | Firmware constants, pin map, product names, protocol UUIDs. |
| `CommandService` | Transport-independent command parsing and response envelope. |
| `RadioService` | nRF24 setup, config, TX/RX, FIFO control, packet polling. |
| `BridgeService` | RF packet forwarding to WebSocket and BLE. |
| `WebService` | SoftAP, HTTP API, browser UI, WebSocket server. |
| `BleService` | BLE UART-style command and notification transport. |
| `Utils` | Hex, RF address, datarate, power, and JSON helpers. |

## Pin Map

The V1 firmware defaults are in `include/Config.h`:

| Signal | GPIO |
| --- | --- |
| nRF24 CE | 45 |
| nRF24 CSN | 15 |
| nRF24 SCK | 14 |
| nRF24 MOSI | 13 |
| nRF24 MISO | 12 |
| RX LED | 16 |
| TX LED | 17 |

## Runtime Defaults

| Setting | Default |
| --- | --- |
| RF channel | 76 |
| RF datarate | `1mbps` |
| RF PA level | `low` |
| Auto-ACK | `true` |
| RF-to-Wi-Fi bridge | `true` |
| RF-to-BLE bridge | `true` |
| Protocol version | `1.1` |
| Firmware version | `0.1.0-v1` |

RF channel and datarate must match between peers. TX power can differ by peer.
Protocol `1.1` can persist RF config, addresses, bridge toggles, device names, and optional auth settings to NVS with `settings_save`.

## Release Build Smoke Test

```bash
cd Firmware/ESP32_RFLINK
pio run -e node1 -e node2
```

Then run the SDK tests:

```bash
cd ../../sdk/python
python -m pytest
```

For hardware validation, flash one `node1` and one `node2`, then run:

```bash
python examples/rf_ping.py --node1-serial COM5 --node2-serial COM6
```

The local web workbench can run the same validation manually: keep both serial ports open, apply matching RF config on both nodes, send ACK-required packets in both directions, and watch `rf_tx`/`rf_rx` counters plus WebSocket/BLE packet events.

## Protocol 1.1 Additions

- `settings_get`, `settings_set`, `settings_save`, and `settings_reset` manage NVS-backed settings.
- `diagnostics` returns support-oriented self-test, status, settings, reset reason, heap, chip, counters, and last-error data.
- `identify` blinks the LED and returns product, role, firmware, AP, BLE, and MAC-derived identity.
- Optional token auth protects HTTP, WebSocket, and BLE command surfaces while USB serial remains the trusted setup path.

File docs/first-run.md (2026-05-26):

# First Run

This guide is the product path for a new two-dongle developer kit.

## 1. Install Host Tools

```bash
cd sdk/python
python -m pip install -e ".[all]"
```

Check what the host can see:

```bash
wdb discover
```

## 2. Identify Each Dongle

Use USB serial for first setup. It remains the trusted setup path even when Wi-Fi/BLE auth is enabled.

```bash
wdb --serial COM5 identify
wdb --serial COM6 identify
```

The `identify` command blinks the device LED and returns firmware, role, AP SSID, BLE name, and device identity.

## 3. Run Diagnostics

```bash
wdb --serial COM5 diagnostics
```

Diagnostics includes self-test output, reset reason, heap, chip information, status, settings, counters, and recent command error state.

## 4. Pair-Test Two Dongles

Flash one dongle as `node1` and one as `node2`, then run:

```bash
wdb pair-test --node1-serial COM5 --node2-serial COM6
```

The pair test configures complementary addresses, applies matching RF config, flushes FIFOs, starts listening, and sends ACK-required packets in both directions.

## 5. Save Bench Settings

Apply settings through the CLI or local web workbench, then save them:

```bash
wdb --serial COM5 settings-set --json '{"rf":{"channel":76,"datarate":"1mbps","power":"low"},"bridge":{"rf_to_wifi":true,"rf_to_ble":true}}'
wdb --serial COM5 settings-save
```

Device name, AP SSID, AP password, and BLE name changes are persisted but require a reboot before every service advertises the new value.

## 6. Export A Support Report

```bash
wdb --serial COM5 report --output reports/node1-report.json
```

The local web workbench has the same export under **Export Support Report**.

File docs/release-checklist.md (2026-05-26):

# V1 Release Checklist

Use this checklist before publishing an external developer release.

## Repository

- [Project overview](../project-overview.md) explains the product, quick start, repo layout, interfaces, and V1 boundaries.
- Firmware, application, SDK, hardware, manufacturing, and docs are discoverable from the repo root.
- Root `README.md`, software license, hardware license notice, issue templates, and CI workflows are present.
- Generated caches, local KiCad files, old backup archives, Python bytecode, and egg-info files are not tracked.
- No user-local absolute paths remain in tracked source files.
- A license file is added before public distribution.

## Firmware

- `pio run -e node1 -e node2` passes from a clean checkout.
- Fresh flash succeeds on at least one dongle per node role.
- Serial boot message includes product, firmware version, protocol version, role, radio health, AP IP, and BLE name.
- `wdb --serial <port> self-test` passes.
- Firmware browser dashboard loads at `http://192.168.4.1`.
- WebSocket packet stream receives RF packet events.
- BLE command transport responds to `status`.
- Protocol 1.1 commands `settings_get`, `settings_set`, `settings_save`, `settings_reset`, `diagnostics`, and `identify` pass over USB serial.
- Optional auth is validated over HTTP, WebSocket, and BLE.

## SDK

- `python -m pip install -e ".[all]"` succeeds in a fresh virtual environment.
- `python -m pytest` passes without hardware.
- CLI works over serial, HTTP, WebSocket, and BLE where hardware is available.
- `wdb discover`, `wdb identify`, `wdb diagnostics`, `wdb pair-test`, and `wdb report` work in supported environments.
- Examples support `--help` and document required optional dependencies.

## Local Web Workbench

- `python -m pip install -r application/requirements.txt` succeeds in a fresh virtual environment.
- `python application/main.py` starts from the repository root.
- `GET http://127.0.0.1:5173/health` returns `{"ok": true}` while the workbench is running.
- The workbench can run `status`, `self_test`, RF config, RF send, address, and bridge commands through the shared SDK client.
- The workbench keeps separate open connections per endpoint so switching between two serial ports does not reset boards during runtime RF testing.
- The Live Events tab receives WebSocket packet events and BLE packet events where hardware is available.
- The workbench can export a support report JSON.
- Serial, HTTP, WebSocket, and BLE transport labels match the SDK and API documentation.

## RF Validation

- One `node1` and one `node2` pass `examples/rf_ping.py` over USB serial.
- `examples/production_demo.py --flash` generates a passing JSON report for a packaged two-dongle kit.
- ACK-required traffic succeeds in both directions.
- Packet monitor shows expected payloads and timestamps.
- Status counters show expected `rf_tx`, `rf_rx`, `rf_tx_fail`, Wi-Fi client count, and BLE connection state.
- RF config values reset to known defaults after reboot.

## Hardware

- KiCad ERC/DRC has been reviewed for the V1 release commit.
- Tracked KiCad source does not contain user-local absolute paths.
- Gerber and drill files match the current KiCad PCB.
- Board images match the released hardware revision.
- Fab notes for stackup, thickness, copper, finish, and assembly options are captured outside the Gerber folder or in the release notes.
- BOM, assembly notes, board revision notes, and pinout card are present or attached as release artifacts.

## Security And Support

- V1 lab-network trust boundaries are documented.
- Known limitations are documented.
- Support and issue-reporting expectations are clear.

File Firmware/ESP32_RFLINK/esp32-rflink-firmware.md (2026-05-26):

# Wireless Dev Bridge Firmware V1

Firmware for a USB-C multi-protocol wireless development interface based on an ESP32-S3-WROOM-1 and nRF24L01+.

For the full product launch package, start at the repository root [Project Overview](../../project-overview.md). For the complete command protocol, see [API Reference](../../docs/api-reference.md).

## Target

- Framework: PlatformIO + Arduino
- Board profile: `esp32-s3-devkitc-1`
- MCU: ESP32-S3-WROOM-1
- Flash target: 4 MB
- RF: nRF24L01+
- USB: native USB CDC serial

## Features

- Newline-delimited USB serial JSON command API
- nRF24L01+ send, receive, configure, listen control, FIFO flush, and address configuration
- Wi-Fi AP mode with firmware browser dashboard at `http://192.168.4.1`
- BLE GATT JSON command transport
- WebSocket live RF packet stream on port `81`
- RF-to-WiFi/WebSocket and RF-to-BLE bridge toggles
- Production-oriented `self_test` command
- Protocol 1.1 settings persistence, diagnostics, identify, optional auth, and support metadata

## Build And Upload

1. Open this folder in PlatformIO.
2. Review hardware values in `include/Config.h`.
3. Build the default environment (`node1`):

```bash
pio run
```

4. Upload:

```bash
pio run --target upload
```

If the device was previously flashed with an 8 MB image or shows core dump CRC warnings, erase once before uploading:

```bash
pio run --target erase
pio run --target upload
```

BLE support requires a larger app partition than the Arduino default OTA layout provides on 4 MB flash. This firmware uses `no_ota.csv`, giving one larger app slot and no OTA slot.

5. Monitor serial:

```bash
pio device monitor -b 115200
```

## Node-Specific Builds

Two PlatformIO environments are provided for RF pair testing:

- `node1`: RX `NODE1`, TX `NODE2`, Wi-Fi AP `WirelessDev-Node1`
- `node2`: RX `NODE2`, TX `NODE1`, Wi-Fi AP `WirelessDev-Node2`

Build both:

```bash
pio run -e node1 -e node2
```

Upload to specific ports when both boards are connected:

```bash
pio device list
pio run -e node1 --target upload --upload-port COM5
pio run -e node2 --target upload --upload-port COM6
```

## Pin Configuration

Edit `include/Config.h` for the final PCB:

- `PIN_NRF_CE`
- `PIN_NRF_CSN`
- `PIN_NRF_SCK`
- `PIN_NRF_MOSI`
- `PIN_NRF_MISO`
- `PIN_LED_Rx`
- `PIN_LED_Tx`
- `PIN_LED`

The default nRF24 address width is 5 bytes. The fallback generic defaults are printable developer values:

- RX: `NODE1`
- TX: `NODE2`

For paired testing, prefer the `node1` and `node2` PlatformIO environments so the addresses are complementary at build time.

## Wi-Fi AP

- SSID: `WirelessDev-Bridge`
- Node 1 SSID: `WirelessDev-Node1`
- Node 2 SSID: `WirelessDev-Node2`
- Password: `12345678`
- Firmware browser dashboard: `http://192.168.4.1`
- WebSocket: `ws://192.168.4.1:81/`

## Boot Log

On startup the firmware emits a serial boot JSON message:

```json
{
  "type": "boot",
  "ok": true,
  "cmd": "boot",
  "data": {
    "product": "WirelessDevBridge",
    "fw": "0.1.0-v1",
    "uptime_ms": 1000,
    "radio_initialized": true,
    "radio_chip_connected": true,
    "ap_ssid": "WirelessDev-Bridge",
    "ap_ip": "192.168.4.1",
    "ble_enabled": true,
    "ble_name": "WirelessDev-Node1"
  },
  "error": null
}
```

## Getting Started By Workflow

Monitor RF packets from a dongle:

```bash
cd ../../sdk/python
python examples/packet_monitor.py --ws 192.168.4.1 --count 10
```

The local web workbench **Live Events** tab provides the same WebSocket/BLE packet visibility while USB serial remains available for command control.

Bridge RF events to BLE:

```bash
wdb --ble WirelessDev-Node1 bridge rf-to-ble on
python examples/packet_monitor.py --ble WirelessDev-Node1 --count 10
```

Run a bench inventory/self-test:

```bash
python examples/device_inventory.py --device serial:COM5 --device serial:COM6
```

## Product Applications

- nRF24 manufacturing tester: one dongle acts as the fixture controller while another or a known-good device acts as the golden peer.
- BLE-to-nRF24 bridge for mobile apps: a phone or tablet talks BLE to the ESP32-S3, then the dongle drives nRF24 test devices.
- RF regression harness: CI or bench scripts replay known packet patterns through the SDK.
- Classroom wireless lab tool: one USB-C dongle exposes serial, Wi-Fi, BLE, and 2.4 GHz RF workflows.
- Portable field diagnostic bridge: a laptop or BLE host inspects nearby nRF24-based nodes without a custom adapter.
- Interactive protocol workbench: combine WebSocket events with a browser UI for packet watch, send, and config changes.
- Sensor gateway prototype: nRF24 edge nodes report to the dongle while applications consume data through HTTP, WebSocket, or BLE.

## Known Limitations

- nRF24 payloads are limited to 32 bytes.
- nRF24 addresses are fixed at 5 bytes in this V1 firmware.
- Wi-Fi AP has no authentication beyond the configured AP password.
- HTTP, WebSocket, and BLE APIs are unauthenticated by default, with optional token auth in protocol 1.1.
- No OTA, cloud, packet decoding, or mesh networking yet.

## Canonical Documentation

- Command protocol, HTTP routes, WebSocket events, BLE UUIDs, and error codes: [API Reference](../../docs/api-reference.md)
- Firmware build environments and module guide: [Firmware Guide](../../docs/firmware.md)
- System architecture diagrams: [Architecture](../../docs/architecture.md)

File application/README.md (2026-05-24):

# Wireless Dev Bridge Workbench

`main.py` is a local browser-hosted workbench for the V1 command protocol. It
starts a FastAPI/Uvicorn server on `http://127.0.0.1:5173`, opens a browser
window automatically, serves the static UI from `application/static`, and wraps
the local Python SDK from `sdk/python`.

This is a host-side tool. The local workbench URL is different from the dongle's
firmware browser dashboard at `http://192.168.4.1`.

## Install

Install web dependencies (one time):

```bash
python -m pip install -r application/requirements.txt
```

Install SDK transport dependencies (one time):

```bash
cd sdk/python
python -m pip install -e ".[all]"
```

HTTP transport does not need SDK extras, but USB serial, WebSocket, and BLE use
the SDK optional dependencies installed by `.[all]`.

## Run

From the repository root:

```bash
python application/main.py
```

The browser opens automatically. If it does not, open:

```text
http://127.0.0.1:5173
```

## Dependencies

| Package | Version | Purpose |
|---|---|---|
| fastapi | >=0.111 | REST API and SSE |
| uvicorn | >=0.29  | ASGI server |

## Architecture

- `application/main.py` is the entry point and backend.
- `application/static/index.html` contains the local HTML, CSS, and JavaScript UI.
- The backend imports the local SDK from `sdk/python` when running from a checkout.
- Blocking SDK calls run through worker threads so the web server can continue
  serving the UI and Server-Sent Events.
- SDK clients are kept open by `(transport, endpoint, timeout)` to avoid USB CDC
  reconnect resets while switching between devices.
- Live packet events use a dedicated WebSocket or BLE SDK connection and are
  broadcast to the browser over Server-Sent Events.
- Active clients and event streams are closed on **Disconnect** and during server
  shutdown.

## Local API

The browser uses these local endpoints. They are intended for the bundled UI and
bench automation, not as a stable public API.

| Method | Path | Purpose |
| --- | --- | --- |
| `GET` | `/health` | Local server health check. |
| `GET` | `/api/ports` | List USB serial ports when `pyserial` is installed. |
| `POST` | `/api/command` | Send one JSON command through USB serial, HTTP, WebSocket, or BLE. |
| `POST` | `/api/disconnect` | Stop live events and close all open SDK clients. |
| `POST` | `/api/events/start` | Start a live event reader over WebSocket or BLE. |
| `POST` | `/api/events/stop` | Ask the live event reader to stop. |
| `GET` | `/api/events/stream` | Browser SSE stream for event status, packets, and errors. |

Command request shape:

```json
{
  "transport": "USB serial",
  "endpoint": "COM5",
  "timeout": 3.0,
  "cmd": "status",
  "params": {}
}
```

Live event start request shape:

```json
{
  "transport": "WebSocket",
  "endpoint": "192.168.4.1",
  "timeout": 3.0
}
```

## Workflows

- Send `ping`, `status`, `self_test`, `protocol`, and `rf_get_config`.
- Keep SDK transports open between commands and endpoints to avoid USB CDC reconnect resets during two-dongle work.
- Refresh `status` automatically so counters, Wi-Fi clients, BLE connection state, and uptime stay current.
- Configure channel, datarate, power, auto-ACK, listen state, and FIFOs.
- Send text or hex nRF24 payloads with the 32-byte V1 limit enforced.
- Set 5-byte RX/TX addresses with Node 1 and Node 2 presets.
- Toggle RF-to-Wi-Fi/WebSocket and RF-to-BLE bridge forwarding.
- Stream live RF packet events over WebSocket or BLE while sending commands through another transport.
- Send raw top-level JSON commands for firmware features not surfaced by a form.

Use **Disconnect** before opening the same serial ports in another tool.

BLE mode connects to the dongle's UART-style GATT service. It is intended for
custom host tools, mobile apps, or the SDK examples to send JSON commands and
receive command responses or RF packet notifications.

## Two-Dongle RF Bring-Up

1. Flash one dongle as `node1` and the other as `node2`.
2. Select COM port for node 1, click **Status**, and confirm RX `NODE1`, TX `NODE2`.
3. Select COM port for node 2, click **Status**, and confirm RX `NODE2`, TX `NODE1`.
4. Set the same channel, datarate, and auto-ACK state on both dongles with **Apply Config**.
5. Send a packet from each side with **Require ACK** enabled.
6. Confirm `rf_tx` increments on the sender and `rf_rx` increments on the receiver.

The app keeps separate open SDK clients for each endpoint. This avoids USB CDC
reconnect resets when switching between COM ports.

## RF Config Notes

- Channel must match on both RF peers.
- Datarate must match on both RF peers: `250kbps`, `1mbps`, or `2mbps`.
- Power can differ by peer: `min`, `low`, `high`, or `max`.
- Runtime RF settings reset when a dongle reboots.
- The app protects in-progress RF config edits from automatic status refreshes.

## Live Events

Use the **Live Events** tab to prove the wireless bridge paths:

- WebSocket: connect the PC to one dongle AP, start a WebSocket stream to
  `192.168.4.1`, then send an RF packet from the other dongle.
- BLE: start a BLE stream to `WirelessDev-Node1` or `WirelessDev-Node2`, then
  send an RF packet from the peer. BLE streaming requires `bleak` from the
  SDK's `.[all]` or `.[ble]` extra.

For packet events, the matching bridge toggle must be enabled:

- WebSocket uses `rf_to_wifi`.
- BLE uses `rf_to_ble`.

Expected packet event shape:

```json
{"type":"packet","source":"rf","data":{"len":5,"hex":"68656C6C6F","uptime_ms":12345}}
```

## Troubleshooting

- **FastAPI/Uvicorn missing:** run `python -m pip install -r application/requirements.txt`.
- **No serial ports:** install the SDK serial extra with `python -m pip install -e "sdk/python[serial]"`, reconnect the dongle, then click **Refresh**.
- **Port 5173 already in use:** stop the other process before running `python application/main.py`.
- **WebSocket live events fail:** connect the PC to the dongle AP or otherwise route to `192.168.4.1`.
- **BLE commands or events fail:** install the BLE extra, confirm a working BLE adapter, and use the advertised device name or address.
- **Another tool cannot open the COM port:** click **Disconnect** or stop the workbench first.

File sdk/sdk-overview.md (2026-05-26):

# SDK

Host-side SDKs and automation tools for Wireless Dev Bridge.

The V1 Python SDK, CLI, tests, and examples live in:

```text
sdk/python
```

Install from the repository root:

```bash
cd sdk/python
python -m pip install -e ".[all]"
```

See [Python SDK guide](python/python-sdk-guide.md) for examples, optional transports, and test instructions.

The local web workbench in [`../application`](../application/desktop-workbench.md) uses this SDK instead of duplicating the command protocol. It exposes serial, HTTP, WebSocket, BLE, RF config, packet send, bridge toggles, and live WebSocket/BLE packet events.

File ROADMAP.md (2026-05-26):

# Wireless Dev Bridge Cleanup Roadmap

Use this as the implementation checklist. Check items only when the listed
validation passes or the limitation is recorded next to the item.

## Phase 0 - Audit And Baseline

- [x] Capture initial repository audit and quality gaps.
- [x] Confirm SDK tests baseline: `cd sdk/python && python -m pytest`.
- [x] Record current git branch and create a cleanup branch.
- [x] Save baseline outputs for conflict check, docs link check, app compile,
  SDK tests, and firmware build availability.

## Phase 1 - P0 Broken State Cleanup

- [x] Remove all merge conflict markers from `README.md`.
  - Validate: `rg -n "^(<<<<<<<|=======|>>>>>>>)" README.md`
- [x] Remove all merge conflict markers from `docs/firmware.md`.
  - Validate: `rg -n "^(<<<<<<<|=======|>>>>>>>)" docs/firmware.md`
- [x] Remove all merge conflict markers from `docs/documentation-index.md`.
  - Validate: `rg -n "^(<<<<<<<|=======|>>>>>>>)" docs/documentation-index.md`
- [x] Resolve `application/main.py` in favor of the FastAPI/Uvicorn local web
  workbench backend.
  - Validate: `python -B -m py_compile application/main.py`
- [x] Fix stale Markdown links to `application/README.md` and
  `sdk/python/README.md`.
  - Validate: `python scripts/check_docs_links.py`
- [x] Normalize public terminology:
  - `local web workbench`: host app at `http://127.0.0.1:5173`
  - `firmware browser dashboard`: device UI at `http://192.168.4.1`
  - Avoid `desktop workbench` unless describing legacy naming.
  - Validate: `rg -n "desktop workbench|local web workbench|browser dashboard" README.md project-overview.md docs application sdk`
- [x] Reconcile version language:
  - Firmware: `0.1.0-v1`
  - Protocol: `1.1`
  - Hardware/package boundary: `V1`
  - Protocol additions: `protocol 1.1`
  - Validate: manual review of `README.md`, `project-overview.md`, `docs/firmware.md`, `docs/api-reference.md`

## Phase 2 - Build And Test Baseline

- [x] Run conflict-marker check across repository.
  - Validate: `rg -n "^(<<<<<<<|=======|>>>>>>>)" .`
- [x] Run Markdown link check.
  - Validate: `python scripts/check_docs_links.py`
- [x] Compile local web workbench backend.
  - Validate: `python -B -m py_compile application/main.py`
- [x] Run SDK/CLI tests.
  - Validate: `cd sdk/python && python -m pytest`
- [x] Verify PlatformIO availability.
  - Validate: `pio --version` or `python -m platformio --version`
  - Note: PlatformIO not available in local PATH.
- [ ] Build both firmware roles when PlatformIO is available.
  - Validate: `cd Firmware/ESP32_RFLINK && pio run -e node1 -e node2`
  - Note: Skipped — PlatformIO not installed locally.

## Phase 3 - Documentation Restructure

- [x] Rewrite `README.md` into one clean executive entry page:
  product summary, board image, quick start, surfaces, checks, docs links,
  limitations.
  - Validate: link check and manual review.
- [x] Update `project-overview.md` to match README terminology and V1/protocol
  boundaries.
  - Validate: manual diff review.
- [x] Add `docs/architecture.md` with Mermaid diagrams for host tools,
  transports, command layer, RF/settings/diagnostics services, and hardware.
  - Validate: Markdown preview/review.
- [x] Update `docs/documentation-index.md` to include architecture, SDK,
  local web workbench, hardware, manufacturing, troubleshooting, release docs.
  - Validate: `python scripts/check_docs_links.py`
- [x] Expand `docs/api-reference.md` with command request fields, response
  highlights, CLI mapping, auth behavior, event shapes, and error taxonomy.
  - Validate: compare against `Firmware/ESP32_RFLINK/src/CommandService.cpp`
    and `sdk/python/wireless_dev_bridge/cli.py`.
- [x] Reduce duplication in `Firmware/ESP32_RFLINK/esp32-rflink-firmware.md`
  or clearly mark canonical docs.
  - Validate: manual review for stale command/version text.
- [x] Add `docs/case-study.md`:
  problem, constraints, architecture, implementation, validation evidence,
  unverified items, business value.
  - Validate: no unsupported claims.
- [x] Update hardware/manufacturing docs to separate verified status from open
  release tasks.
  - Validate: manual review of `docs/hardware.md`, `hardware/BOM.md`,
    `hardware/LICENSE.md`, `manufacturing/manufacturing-guide.md`.
- [ ] Add screenshots only after the app/dashboard visuals are validated.
  - Validate: files exist under `docs/assets/screenshots/` and are referenced.
  - Note: Skipped — requires running app/dashboard and capturing visuals.

## Phase 4 - Firmware/API Improvements

- [x] Add structured RF metrics:
  TX attempts, TX success, ACK failures, RX invalid, last packet timestamp,
  last packet length, ACK failure rate.
  - Validate: firmware build and two-node hardware check when available.
  - Note: Code implemented, requires PlatformIO build and hardware validation.
- [x] Add settings schema version and validation for loaded persisted values.
  - Validate: save/reboot/settings-get hardware check.
  - Note: Code implemented, requires hardware validation.
- [x] Make direct `rf_config`, `rf_set_address`, and `bridge` changes mark
  settings dirty consistently.
  - Validate: command sequence plus `status.storage.dirty`.
  - Note: Code implemented, requires hardware validation.
- [x] Prevent partial runtime state mutation when command validation fails.
  - Validate: invalid command tests and unchanged follow-up `rf_get_config`.
  - Note: Code implemented with validate-then-apply pattern in handleRfConfig.
- [x] Add event log ring buffer for boot, command errors, auth failures,
  RF send failures, settings saves/resets.
  - Validate: `diagnostics` or new `event_log` command returns entries.
  - Note: Code implemented, requires hardware validation.
- [x] Add build metadata to `protocol`/`diagnostics`:
  build profile, build date, optional git SHA from CI build flags.
  - Validate: `wdb --serial <port> protocol`.
  - Note: Code implemented, requires PlatformIO build.
- [x] Add RF metrics command only with nRF24-supported fields.
  - Do not call RPD/carrier-detect a true RSSI value.
  - Validate: docs and hardware check.
  - Note: `rf_metrics` command implemented, no RPD/RSSI claims.
- [ ] Add built-in two-node link test/report if it improves over SDK `pair-test`.
  - Validate: two-dongle hardware report.
  - Note: Deferred — SDK `pair-test` is sufficient for V1.
- [x] Add named RF profiles: lab, low-power, range-test, production-test.
  - Validate: apply profile and inspect `rf_get_config`.
  - Note: `rf_profiles` and `rf_apply_profile` commands implemented.
- [x] Harden optional lab auth docs/behavior without claiming production security.
  - Validate: unauthorized and token-authenticated HTTP/WebSocket/BLE checks.
  - Note: Auth behavior documented in API reference. Security model doc already covers lab-only scope.

## Phase 5 - SDK/CLI Updates

- [x] Add SDK model fields for new diagnostics/RF metrics.
  - Validate: SDK tests pass (25/25).
- [x] Add CLI commands/options for new firmware diagnostics only after firmware
  command names are stable.
  - Validate: CLI unit tests pass. Added rf-metrics, rf-profiles, rf-apply-profile, event-log.
- [x] Update support report to include new metrics, build metadata, event log,
  and validation status.
  - Validate: report includes settings, rf_metrics, event_log, and expanded summary.
- [x] Update examples to use current command names and avoid unsupported claims.
  - Validate: `cd sdk/python && python -m pytest` — 25 passed.
- [x] Keep hardware-free tests for command mapping and report formatting.
  - Validate: All 25 existing tests still pass.

## Phase 6 - CI And Release Polish

- [x] Add `scripts/check_conflict_markers.py`.
  - Validate: script passes on clean tree.
- [x] Wire conflict-marker check into `.github/workflows/ci.yml`.
  - Validate: CI syntax review.
- [x] Add docs consistency check for stale file links and banned outdated terms.
  - Validate: `python scripts/check_docs_consistency.py` passes.
- [x] Keep CI jobs for SDK tests, app compile, docs links, and firmware build.
  - Validate: workflow includes all checks.
- [x] Upload `node1` and `node2` firmware binaries as CI artifacts after build.
  - Validate: workflow artifact paths configured.
- [x] Update `scripts/package_release.py` to include README, overview, docs,
  hardware docs/license notice, KiCad source, Gerbers, and validation checklist.
  - Validate: `python scripts/package_release.py --output dist/release` produces expected outputs.
- [x] Keep generated release archives out of git.
  - Validate: `dist/` is in `.gitignore`.

## Phase 7 - Final Showcase Review

- [x] Run all available local checks:
  conflict markers, docs links, app compile, SDK tests, firmware build if
  PlatformIO is installed.
  - All pass. PlatformIO not installed — firmware build skipped.
- [ ] Run hardware checks if hardware is available:
  identify, diagnostics, settings save/reboot, pair-test, packet monitor,
  optional auth over HTTP/WebSocket/BLE.
  - Note: Hardware not available. All hardware checks are unverified.
- [x] Add validation evidence or mark hardware checks as unverified.
  - Case study, beta validation, and release checklist document unverified items.
- [x] Review README and case study for unsupported claims.
  - No unsupported claims found. Hardware items marked as requiring validation.
- [x] Confirm public navigation from README reaches firmware, SDK, workbench,
  hardware, manufacturing, troubleshooting, security, and release docs.
  - All navigation links verified by `check_docs_links.py`.
- [x] Confirm repo presents as a professional embedded systems case study.
  - Architecture diagrams, case study, normalized terminology, and clean docs structure.

## Done Criteria

- [x] No conflict markers remain.
- [x] README is clean, non-duplicated, and all links resolve.
- [x] Documented JSON commands match firmware implementation.
- [x] Documented CLI commands match SDK implementation.
- [ ] Firmware builds for `node1` and `node2` where PlatformIO is available.
  - Note: PlatformIO not installed locally. CI workflow configured.
- [x] SDK tests pass.
- [x] Local web workbench compiles and starts/imports cleanly.
- [x] Docs links are valid.
- [x] Hardware claims are labeled verified, unverified, or checklist-only.
- [x] Release package contains the expected docs, firmware artifacts, hardware
  source, and manufacturing outputs.

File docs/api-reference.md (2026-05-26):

# API Reference

Wireless Dev Bridge uses the same JSON command model over USB serial, HTTP, WebSocket, and BLE.

## Response Envelope

Successful commands:

```json
{
  "ok": true,
  "cmd": "status",
  "data": {},
  "error": null
}
```

Errors:

```json
{
  "ok": false,
  "cmd": "rf_send",
  "data": {},
  "error": {
    "code": "payload_too_large",
    "message": "payload must be 32 bytes or less"
  }
}
```

## Transports

| Transport | Framing | Endpoint |
| --- | --- | --- |
| USB CDC serial | Newline-delimited JSON | 115200 baud |
| HTTP | JSON request/response | `http://192.168.4.1` |
| WebSocket | JSON messages | `ws://192.168.4.1:81/` |
| BLE GATT | Newline-delimited JSON | UART-style service |

## Commands

| Command | Purpose |
| --- | --- |
| `ping` | Basic liveness check. |
| `protocol` | Capability and protocol metadata. |
| `capabilities` | Alias for `protocol`. |
| `status` | Runtime status, radio config, bridge state, BLE state, Wi-Fi state, and counters. |
| `self_test` | Production-oriented radio, Wi-Fi, BLE, heap, and role check. |
| `rf_get_config` | Read current RF config. |
| `rf_config` | Set channel, datarate, power, and auto-ACK. |
| `rf_send` | Send a hex payload over nRF24. |
| `rf_start_listen` | Enter receive/listen mode. |
| `rf_stop_listen` | Stop receive/listen mode. |
| `rf_flush_rx` | Flush nRF24 RX FIFO. |
| `rf_flush_tx` | Flush nRF24 TX FIFO. |
| `rf_set_address` | Set RX and/or TX pipe addresses. |
| `bridge` | Enable or disable RF-to-Wi-Fi and RF-to-BLE event forwarding. |
| `settings_get` | Read effective runtime settings and persisted-settings state. |
| `settings_set` | Apply partial RF, bridge, device, or security settings. |
| `settings_save` | Persist current settings to NVS. |
| `settings_reset` | Clear persisted settings and restore defaults. |
| `diagnostics` | Return self-test, status, settings, reset reason, chip, heap, counters, and last error data. |
| `identify` | Blink the LED and return identity fields for matching a physical dongle. |

## Status Data

`status` returns the current runtime state. Useful fields:

| Field | Meaning |
| --- | --- |
| `radio.channel` | nRF24 channel, `0..125`. |
| `radio.datarate` | nRF24 datarate: `250kbps`, `1mbps`, or `2mbps`. Both RF peers must match. |
| `radio.power` | TX power: `min`, `low`, `high`, or `max`. |
| `radio.listening` | Whether the radio is in RX/listen mode. |
| `radio.rx_address_ascii` / `radio.tx_address_ascii` | Printable 5-byte pipe addresses when available. |
| `wifi.clients` | Number of stations associated to the SoftAP. |
| `ble.connected` | Whether a BLE central is connected. |
| `stats.rf_tx` / `stats.rf_rx` | RF packets transmitted and received. |
| `stats.rf_tx_fail` | RF send failures, including ACK timeouts. |
| `device.id` | MAC-derived identity used for support and physical device matching. |
| `storage.dirty` | Runtime settings differ from saved NVS settings. |
| `security.auth_required` | Whether non-USB command surfaces require a token. |
| `reset_reason` | Last reset reason reported by the ESP32 runtime. |
| `last_error` | Last command error object, or `null` when no command error has been recorded. |

## CLI Command Mapping

| CLI command | Firmware command | Notes |
| --- | --- | --- |
| `wdb discover` | — | Host-side serial port discovery, no firmware command. |
| `wdb ping` | `ping` | |
| `wdb protocol` | `protocol` | |
| `wdb status` | `status` | |
| `wdb self-test` | `self_test` | |
| `wdb identify` | `identify` | |
| `wdb diagnostics` | `diagnostics` | |
| `wdb rf-get-config` | `rf_get_config` | |
| `wdb rf-config` | `rf_config` | `--channel`, `--datarate`, `--power`, `--auto-ack` |
| `wdb rf-send` | `rf_send` | `--hex`, `--require-ack` |
| `wdb listen` | `rf_start_listen` / `rf_stop_listen` | `--start` or `--stop` |
| `wdb flush` | `rf_flush_rx` / `rf_flush_tx` | `--rx` or `--tx` |
| `wdb set-address` | `rf_set_address` | `--rx`, `--tx`, `--format` |
| `wdb bridge` | `bridge` | `--rf-to-wifi`, `--rf-to-ble` |
| `wdb settings-get` | `settings_get` | |
| `wdb settings-set` | `settings_set` | `--json` with partial settings object |
| `wdb settings-save` | `settings_save` | |
| `wdb settings-reset` | `settings_reset` | |
| `wdb setup` | `settings_set` + `settings_save` | Applies common first-run settings. |
| `wdb raw` | any | Sends raw JSON via `--json`. |
| `wdb pair-test` | multiple | Two-dongle serial RF validation sequence. |
| `wdb report` | multiple | Collects status, self-test, diagnostics, settings into a JSON report. |
| `wdb firmware flash` | — | Host-side esptool flash, no firmware command. |

## Command Request Fields

| Command | Required fields | Optional fields |
| --- | --- | --- |
| `ping` | — | — |
| `protocol` | — | — |
| `status` | — | — |
| `self_test` | — | — |
| `identify` | — | — |
| `diagnostics` | — | — |
| `rf_get_config` | — | — |
| `rf_config` | — | `channel` (int 0-125), `datarate` (string), `power` (string), `auto_ack` (bool) |
| `rf_send` | `hex` (string) | `require_ack` (bool) |
| `rf_start_listen` | — | — |
| `rf_stop_listen` | — | — |
| `rf_flush_rx` | — | — |
| `rf_flush_tx` | — | — |
| `rf_set_address` | — | `rx` (string), `tx` (string), `format` (`ascii`/`hex`), `pipe` + `address` |
| `bridge` | — | `rf_to_wifi` (bool), `rf_to_ble` (bool) |
| `settings_get` | — | — |
| `settings_set` | — | `rf` (object), `bridge` (object), `device` (object), `security` (object) |
| `settings_save` | — | — |
| `settings_reset` | — | — |

## Command Examples

```json
{"cmd":"status"}
```

```json
{"cmd":"rf_config","channel":76,"datarate":"1mbps","power":"low","auto_ack":true}
```

```json
{"cmd":"rf_send","hex":"68656C6C6F","require_ack":true}
```

```json
{"cmd":"rf_set_address","rx":"NODE1","tx":"NODE2","format":"ascii"}
```

```json
{"cmd":"bridge","rf_to_wifi":true,"rf_to_ble":true}
```

```json
{"cmd":"settings_set","rf":{"channel":76,"datarate":"1mbps","power":"low","rx":"NODE1","tx":"NODE2","address_format":"ascii"},"bridge":{"rf_to_wifi":true,"rf_to_ble":true}}
```

```json
{"cmd":"settings_save"}
```

```json
{"cmd":"diagnostics"}
```

```json
{"cmd":"identify"}
```

## Settings And Auth

Protocol `1.1` adds NVS-backed settings. `settings_set` accepts partial objects:

| Object | Fields |
| --- | --- |
| `rf` | `channel`, `datarate`, `power`, `auto_ack`, `rx`, `tx`, `address_format` |
| `bridge` | `rf_to_wifi`, `rf_to_ble` |
| `device` | `name`, `ap_ssid`, `ap_pass`, `ble_name` |
| `security` | `auth_required`, `auth_token` |

HTTP uses the `X-WDB-Token` header when auth is required. WebSocket and BLE use top-level JSON field `auth`. USB serial remains the trusted setup path.

## HTTP Routes

| Route | Method | Purpose |
| --- | --- | --- |
| `/api/status` | `GET` | Runtime status. |
| `/api/self_test` | `GET` | Self-test response. |
| `/api/command` | `POST` | Generic command endpoint. |
| `/api/rf/config` | `GET` | Read RF config. |
| `/api/rf/config` | `POST` | Apply RF config. |
| `/api/rf/send` | `POST` | Send RF payload. |
| `/api/rf/listen/start` | `POST` | Start listening. |
| `/api/rf/listen/stop` | `POST` | Stop listening. |
| `/api/rf/flush_rx` | `POST` | Flush RX FIFO. |
| `/api/rf/flush_tx` | `POST` | Flush TX FIFO. |
| `/api/bridge` | `POST` | Set bridge state. |

The generic `/api/command` route is the canonical route for protocol `1.1` commands such as `settings_get`, `settings_set`, `diagnostics`, and `identify`.

## RF Packet Event

RF packet events are emitted on USB serial, WebSocket when `rf_to_wifi` is enabled, and BLE notifications when `rf_to_ble` is enabled.

```json
{
  "type": "packet",
  "source": "rf",
  "data": {
    "len": 5,
    "hex": "68656C6C6F",
    "uptime_ms": 12345
  }
}
```

## Status Event

```json
{
  "type": "status",
  "data": {
    "fw": "0.1.0-v1",
    "protocol": "1.1",
    "role": "node1",
    "uptime_ms": 12345,
    "radio": {},
    "wifi": {},
    "bridge": {},
    "ble": {},
    "stats": {}
  }
}
```

## BLE GATT

BLE advertises with the node-specific device name:

- `WirelessDev-Node1`
- `WirelessDev-Node2`

UART-style service:

| Item | UUID |
| --- | --- |
| Service | `6e400001-b5a3-f393-e0a9-e50e24dcca9e` |
| RX write | `6e400002-b5a3-f393-e0a9-e50e24dcca9e` |
| TX notify | `6e400003-b5a3-f393-e0a9-e50e24dcca9e` |

Subscribe to TX notifications before writing commands to RX. Responses are newline-terminated and may be split across multiple notifications.

BLE is a GATT command/event transport, not classic Bluetooth serial. A BLE central writes JSON commands to RX and receives command responses or packet events on TX.

## Error Taxonomy

Error responses include a `code` and `message`. Codes are stable across firmware versions.

| Code | Commands | Meaning |
| --- | --- | --- |
| `unknown_cmd` | any | Command name not recognized. |
| `missing_cmd` | — | Request JSON has no `cmd` field. |
| `invalid_json` | — | Request is not valid JSON. |
| `line_too_long` | — | Serial line exceeds maximum length. |
| `auth_required` | any | Non-USB transport requires a valid token. |
| `invalid_arg` | multiple | Argument has wrong type or format. |
| `missing_arg` | `rf_send`, `rf_set_address` | Required field is absent. |
| `invalid_channel` | `rf_config` | Channel outside 0-125 range. |
| `invalid_datarate` | `rf_config` | Datarate not `250kbps`, `1mbps`, or `2mbps`. |
| `invalid_power` | `rf_config` | Power not `min`, `low`, `high`, or `max`. |
| `empty_payload` | `rf_send` | Hex payload is empty. |
| `invalid_hex` | `rf_send` | Payload contains non-hex characters or odd length. |
| `payload_too_large` | `rf_send` | Payload exceeds 32 bytes. |
| `invalid_address` | `rf_set_address`, `settings_set` | Address not 5 ASCII chars or 10 hex chars. |
| `invalid_pipe` | `rf_set_address` | Pipe must be `rx` or `tx`. |
| `invalid_setting` | `settings_set` | Setting value out of range (name length, password length, token length). |
| `radio_not_initialized` | RF commands | nRF24L01+ failed initialization. |
| `nvs_error` | `settings_save`, `settings_reset` | NVS write/erase failed. |
| `send_failed` | `rf_send` | nRF24 TX failed (no ACK or hardware error). |

## Auth Behavior

USB serial is always trusted and never requires authentication.

When `security.auth_required` is `true`:

- **HTTP**: include the token as `X-WDB-Token` header.
- **WebSocket**: include `"auth": "<token>"` in each command JSON.
- **BLE**: include `"auth": "<token>"` in each command JSON.

Commands without a valid token receive an `auth_required` error. Set `security.auth_token` through `settings_set` over USB serial, then `settings_save` to persist.

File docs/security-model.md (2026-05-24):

# Security Model

Wireless Dev Bridge is designed for trusted developer benches and lab networks.

## Default Behavior

- USB serial is treated as the trusted setup path.
- Wi-Fi SoftAP uses the configured AP password.
- HTTP, WebSocket, and BLE command APIs are unauthenticated by default for fast bench bring-up.
- RF traffic is not encrypted by the dongle.

## Optional Command Auth

Protocol `1.1` adds optional token auth for non-USB command surfaces:

- HTTP: send `X-WDB-Token`.
- WebSocket and BLE: include top-level JSON field `auth`.
- `ping`, `protocol`, and `capabilities` remain available without auth for discovery.

Example:

```bash
wdb --serial COM5 setup --auth-required --device-auth-token lab-secret --save
wdb --host 192.168.4.1 --auth-token lab-secret diagnostics
```

If auth is required and the token is missing or wrong, commands return:

```json
{"ok":false,"cmd":"status","data":{},"error":{"code":"auth_required","message":"valid auth token required"}}
```

## Operational Guidance

- Do not expose the AP, HTTP, WebSocket, or BLE command surfaces to untrusted networks.
- Rotate the token before sharing hardware outside a trusted bench.
- Use `settings_reset` over USB serial to clear persisted settings and auth state.

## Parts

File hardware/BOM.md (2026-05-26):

# Bill Of Materials

The current repository tracks KiCad source and manufacturing outputs, but does not yet include a normalized purchasing BOM.

Before a public hardware release, export and review:

- Manufacturer part number and distributor SKU for every fitted component.
- Quantity per board.
- Reference designators.
- Approved alternates for passives, USB-C connector, ESP32-S3 module, nRF24L01+ path components, and LEDs.
- Do-not-populate parts, if any.
- Assembly notes for orientation-sensitive components.

Keep the generated BOM as a release artifact or add a reviewed CSV in this directory once component sourcing is locked.

## Status

- **Verified**: KiCad schematic includes all fitted components with values and footprints.
- **Open**: Normalized purchasing BOM with distributor SKUs and approved alternates has not been exported for this release.

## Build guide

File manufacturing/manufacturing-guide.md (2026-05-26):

# Manufacturing

This directory contains the current V1 board manufacturing export.

## Gerbers

Gerber and drill files live in:

```text
manufacturing/gerbers
```

The KiCad project is configured to export new Gerbers to this folder from:

```text
hardware/kicad/ESPxRF.kicad_pcb
```

## Release Package

Create a fab upload package from the repository root:

```bash
cd manufacturing/gerbers
zip -r ../wireless-dev-bridge-v1-gerbers.zip .
```

Do not commit generated ZIP archives. Attach them to tagged releases instead.

## Status

- **Verified**: Gerber and drill files exist in `manufacturing/gerbers` and correspond to the current KiCad PCB layout.
- **Open**: Fab order from these outputs has not been confirmed. DRC/ERC review should be repeated before production ordering.

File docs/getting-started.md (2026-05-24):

# Getting Started

This guide takes a new developer from clone to a working Wireless Dev Bridge dongle.

## Requirements

- ESP32-S3 Wireless Dev Bridge hardware.
- USB-C cable with data support.
- PlatformIO Core or the PlatformIO IDE extension.
- Python 3.9 or newer.
- Optional transport packages for USB serial, WebSocket, BLE, and MQTT examples.

## 1. Build Firmware

```bash
cd Firmware/ESP32_RFLINK
pio run -e node1
```

The default firmware target is `node1`. For paired RF testing, build both node roles:

```bash
pio run -e node1 -e node2
```

## 2. Flash A Dongle

List connected serial ports:

```bash
pio device list
```

Upload to a specific port:

```bash
pio run -e node1 --target upload --upload-port COM5
```

If the device was previously flashed with a different partition layout, erase once:

```bash
pio run -e node1 --target erase --upload-port COM5
pio run -e node1 --target upload --upload-port COM5
```

## 3. Install Host Tools

From the repository root:

```bash
cd sdk/python
python -m pip install -e ".[all]"
```

HTTP-only SDK usage has no runtime dependencies, but `.[all]` installs the optional serial, WebSocket, BLE, and MQTT transports used by the examples.

The local web workbench uses the same SDK and optional transport packages, plus
FastAPI/Uvicorn for the local browser UI:

```bash
cd ../..
python -m pip install -r application/requirements.txt
python application/main.py
```

Open `http://127.0.0.1:5173` if the browser does not open automatically. The
workbench is the easiest way to validate a bench interactively. It keeps USB
serial connections open per COM port, refreshes `status`, edits RF config,
sends packets, and streams WebSocket/BLE packet events.

## 4. Run A Smoke Test

USB serial:

```bash
wdb --serial COM5 self-test
wdb --serial COM5 status
wdb --serial COM5 diagnostics
```

Wi-Fi:

```bash
wdb --host 192.168.4.1 status
```

BLE:

```bash
wdb --ble WirelessDev-Node1 status
```

## 5. Use The Browser Dashboard

Connect your computer to the dongle access point, then open:

```text
http://192.168.4.1
```

Default node SSIDs:

- `WirelessDev-Node1`
- `WirelessDev-Node2`

Default AP password:

```text
12345678
```

## 6. Run A Two-Dongle RF Test

Flash one dongle as `node1` and the other as `node2`, then run:

```bash
cd sdk/python
python examples/rf_ping.py --node1-serial COM5 --node2-serial COM6
```

The test verifies role, radio health, RF config, complementary addresses, and ACK-required traffic in both directions.

Manual two-dongle validation in the local web workbench:

1. Select the node 1 COM port and confirm RX `NODE1`, TX `NODE2`.
2. Select the node 2 COM port and confirm RX `NODE2`, TX `NODE1`.
3. Apply the same channel, datarate, and auto-ACK state on both dongles.
4. Send ACK-required packets both directions.
5. Confirm `rf_tx` and `rf_rx` counters increment in `status`.

For a more polished launch demo that can build, flash, validate, and generate a JSON report:

```bash
cd sdk/python
python examples/production_demo.py --node1-serial COM5 --node2-serial COM6 --flash --operator TP --lot EVT1
```

To see connected ports first:

```bash
python examples/production_demo.py --list-ports
```

The CLI can also collect a support report from a single device:

```bash
wdb --serial COM5 report --output reports/node1-report.json
```

For a product-style first-run flow, see [First Run](first-run.md).

## Common Workflows

Monitor RF packets over WebSocket:

```bash
python examples/packet_monitor.py --ws 192.168.4.1 --count 10
```

Or use the local web workbench **Live Events** tab, choose `WebSocket`, stream from `192.168.4.1`, and send RF from the peer dongle.

Bridge RF packet events to BLE:

```bash
wdb --ble WirelessDev-Node1 bridge rf-to-ble on
python examples/packet_monitor.py --ble WirelessDev-Node1 --count 10
```

Or use the local web workbench **Live Events** tab, choose `BLE`, stream from `WirelessDev-Node1` or `WirelessDev-Node2`, and send RF from the peer dongle.

Bridge RF packet events to MQTT:

```bash
python -m pip install -e ".[mqtt]"
python examples/bridge_to_mqtt.py --ws 192.168.4.1 --broker localhost --topic-prefix lab/bridge1
```

Inventory a bench before a test run:

```bash
python examples/device_inventory.py --device serial:COM5 --device serial:COM6
```

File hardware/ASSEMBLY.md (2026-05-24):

# Assembly Notes

## Required Release Checks

- Confirm ESP32-S3 module orientation.
- Confirm USB-C connector alignment and shell grounding.
- Confirm nRF24L01+ SPI routing and CE/CSN pins match `Firmware/ESP32_RFLINK/include/Config.h`.
- Confirm LED polarity and silkscreen labels.
- Confirm antenna/RF keepout assumptions for the selected nRF24 implementation.
- Inspect first articles for solder bridges around USB-C and fine-pitch module pads.

## Bring-Up

1. Check USB enumeration.
2. Flash `node1`.
3. Run `wdb --serial <port> self-test`.
4. Run RF pair-test against a known-good dongle.
5. Save a support report with the board revision and lot identifier.

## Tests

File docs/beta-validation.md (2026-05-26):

# Beta Validation

Use this matrix before calling a release product-ready.

## Host Platforms

| Platform | Required checks |
| --- | --- |
| Windows | USB serial identify, diagnostics, local web workbench start, support report export, pair-test |
| Linux | USB serial identify, diagnostics, local web workbench start, support report export, pair-test |
| macOS | USB serial identify, diagnostics, local web workbench start, support report export, pair-test |

HTTP, WebSocket, and BLE should be validated where host adapters and permissions are available.

## Hardware-In-Loop

- Flash one `node1` and one `node2`.
- Run `wdb pair-test`.
- Verify WebSocket packet events through the firmware browser dashboard or local web workbench.
- Verify BLE packet events with `packet_monitor.py --ble`.
- Save settings, reboot, and confirm `settings_get` reports persisted values.
- Enable auth, confirm unauthorized HTTP/WebSocket/BLE commands fail, then confirm token-authenticated commands pass.

## Release Evidence

Store these with the release notes:

- CI run URL.
- Firmware build hashes or artifacts.
- SDK package artifact.
- Gerber zip artifact.
- DRC/ERC review note.
- At least one support report from a passing two-dongle kit.

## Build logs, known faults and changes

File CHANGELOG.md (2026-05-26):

# Changelog

## 0.1.0-v1

- Initial V1 developer launch package.
- ESP32-S3 PlatformIO firmware with USB serial, Wi-Fi HTTP, WebSocket, and BLE GATT command transports.
- nRF24L01+ send, receive, listen, flush, address, and RF configuration commands.
- RF-to-Wi-Fi/WebSocket and RF-to-BLE bridge toggles.
- Firmware browser dashboard served from the dongle SoftAP.
- Python SDK, CLI, local web workbench, hardware-free tests, and launch examples.
- Local web workbench RF config, packet send, persistent two-port serial control, and WebSocket/BLE live event monitoring.
- KiCad hardware source, board images, and Gerber/drill export.

## Unreleased

- Added protocol `1.1` settings, diagnostics, identify, optional auth, and status metadata.
- Added SDK/CLI helpers for settings, diagnostics, identify, support reports, pair-test, discovery, setup, and firmware flashing.
- Added local web workbench auth token support, diagnostics/identify/settings quick actions, and support report export.
- Expanded firmware browser dashboard with diagnostics, address controls, BLE bridge toggle, settings auth, report export, and clearer status cards.
- Added root README, software/hardware license notices, CI/release workflows, issue templates, release packaging script, and product journey docs.

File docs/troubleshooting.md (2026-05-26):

# Troubleshooting

## Start With A Report

Collect a support report before changing multiple variables:

```bash
wdb --serial COM5 report --output reports/device-report.json
```

Attach the report when opening an issue.

## USB Serial

- Use a USB-C cable with data support.
- Run `wdb discover` to list serial ports.
- Use **Disconnect** in the local web workbench before opening the same port in another tool.
- If serial output contains boot messages before command responses, the SDK filters events and waits for the matching command response.

## RF Pairing

- Both peers must use the same channel and datarate.
- `node1` defaults to RX `NODE1`, TX `NODE2`.
- `node2` defaults to RX `NODE2`, TX `NODE1`.
- Use ACK-required sends for validation because ACK failures increment `stats.rf_tx_fail`.

## Wi-Fi And Firmware Browser Dashboard

- Connect the host computer to the dongle AP before opening `http://192.168.4.1`.
- If optional auth is enabled, enter the token in the firmware browser dashboard settings area.
- AP SSID and password changes require reboot after `settings_save`.

## BLE

- BLE uses GATT, not classic serial.
- Install the SDK `ble` or `all` extra for Python BLE tools.
- BLE notifications may split JSON lines; use the SDK or buffer until newline.

## Reset Settings

Use USB serial:

```bash
wdb --serial COM5 settings-reset
```

This clears persisted settings and restores defaults. Device/AP/BLE name changes may require reboot to be fully reflected by active services.

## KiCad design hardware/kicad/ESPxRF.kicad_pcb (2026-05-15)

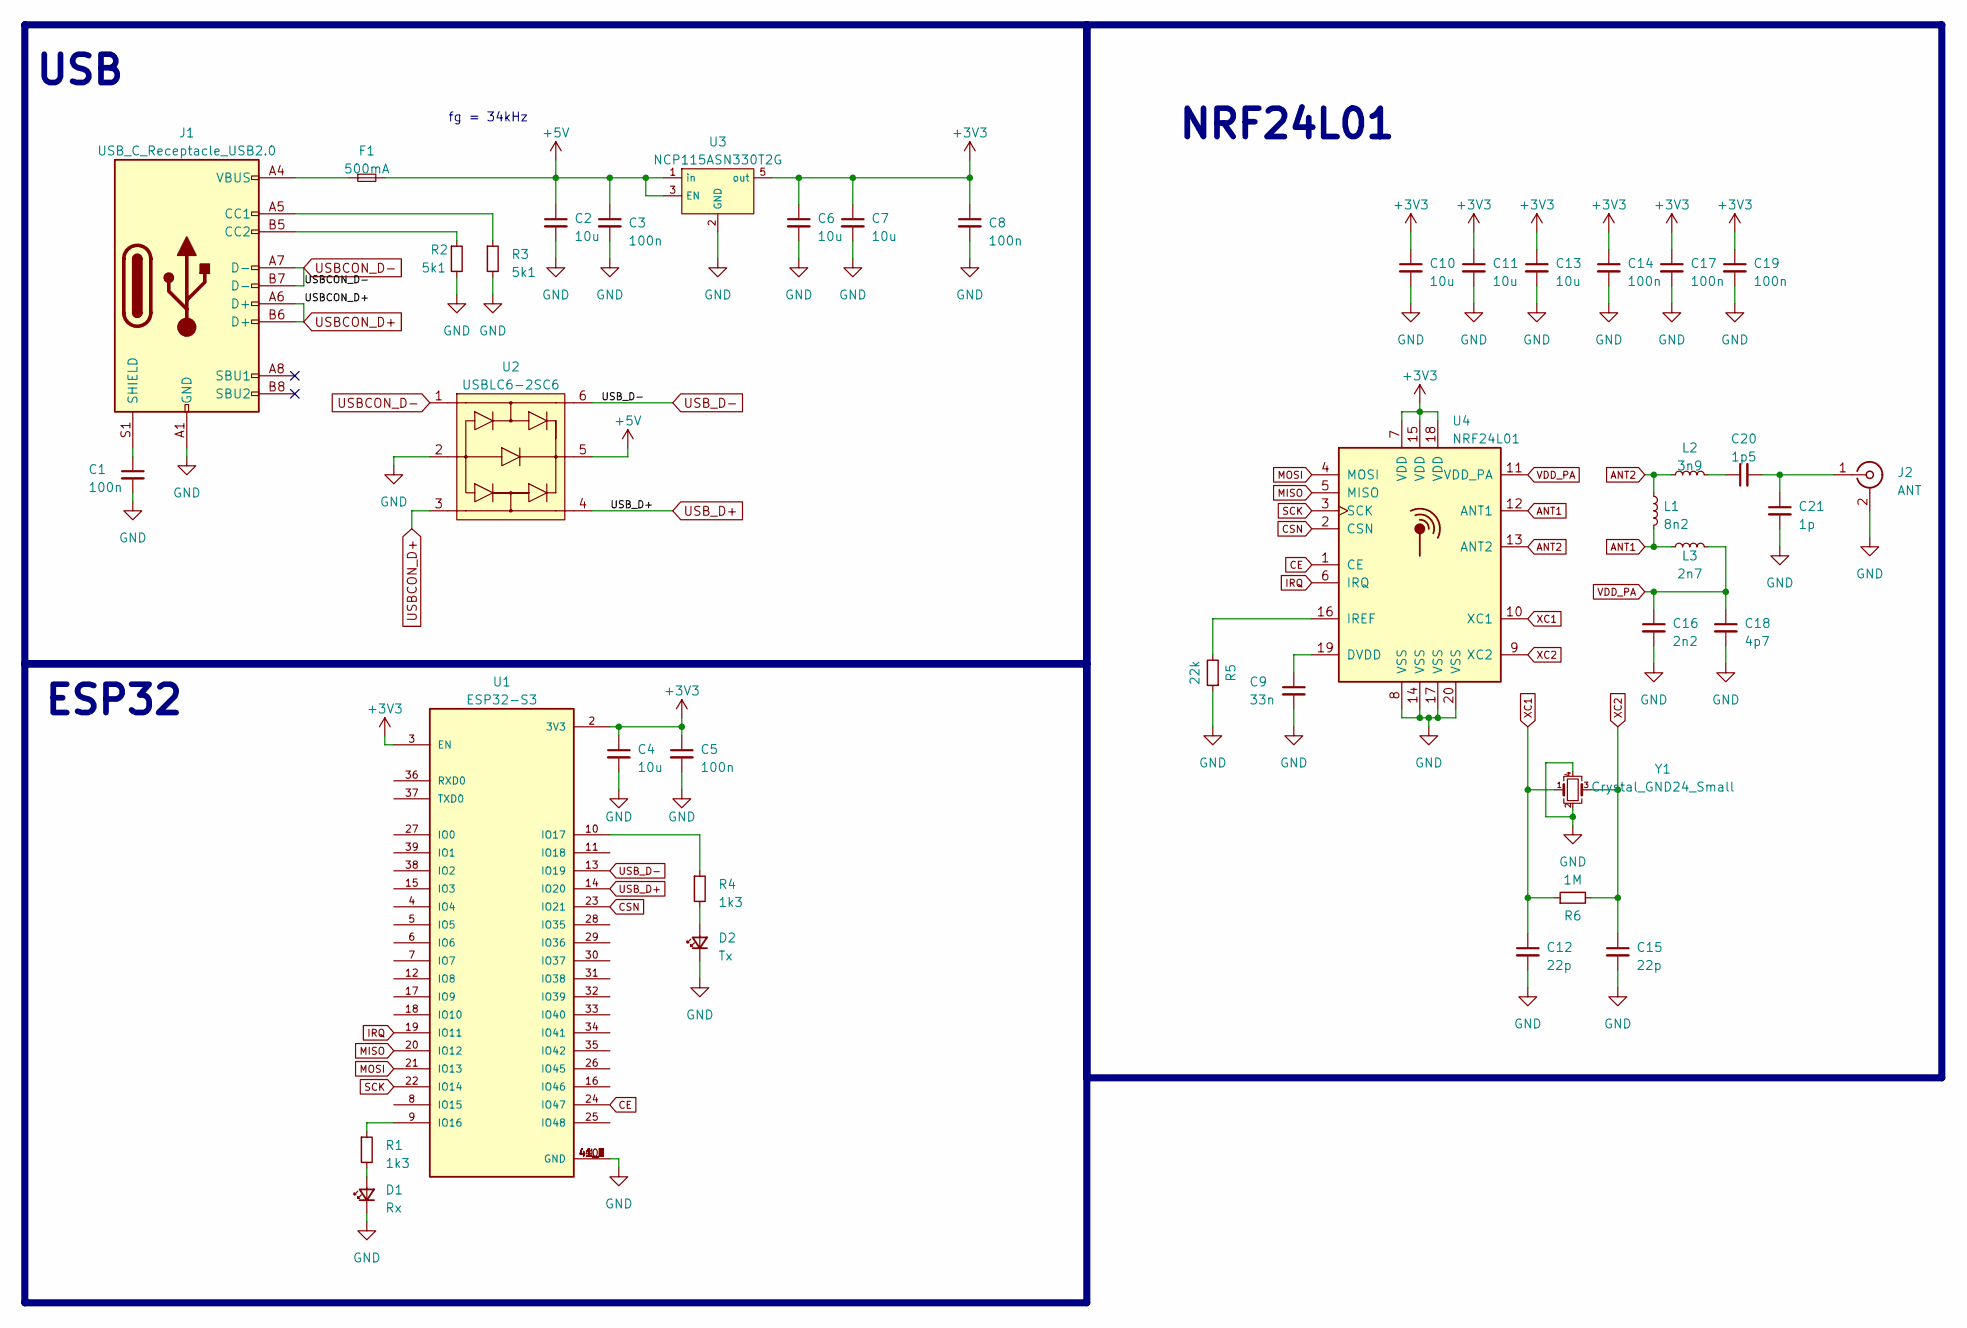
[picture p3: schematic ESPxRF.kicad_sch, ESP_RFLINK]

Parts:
C1, C3, C5, C8, C14, C17, C19: 100n; C_0603_1608Metric_Pad1.08x0.95mm_HandSolder
C2, C4, C6, C7, C10, C11, C13: 10u; C_0805_2012Metric_Pad1.18x1.45mm_HandSolder
C9: 33n; C_0603_1608Metric_Pad1.08x0.95mm_HandSolder
C12, C15: 22p; C_0603_1608Metric_Pad1.08x0.95mm_HandSolder
C16: 2n2; C_0402_1005Metric_Pad0.74x0.62mm_HandSolder
C18: 4p7; C_0402_1005Metric_Pad0.74x0.62mm_HandSolder
C20: 1p5; C_0402_1005Metric_Pad0.74x0.62mm_HandSolder
C21: 1p; C_0402_1005Metric_Pad0.74x0.62mm_HandSolder
D1: Rx; LED_0603_1608Metric_Pad1.05x0.95mm_HandSolder
D2: Tx; LED_0603_1608Metric_Pad1.05x0.95mm_HandSolder
F1: 500mA; Fuse_0603_1608Metric_Pad1.05x0.95mm_HandSolder
J1: USB_C_Receptacle_USB2.0; USB_C_Receptacle_GCT_USB4105-xx-A_16P_TopMnt_Horizontal
J2: ANT; SMA_Samtec_SMA-J-P-H-ST-EM1_EdgeMount
L1: 8n2; L_0402_1005Metric_Pad0.77x0.64mm_HandSolder
L2: 3n9; L_0402_1005Metric_Pad0.77x0.64mm_HandSolder
L3: 2n7; L_0402_1005Metric_Pad0.77x0.64mm_HandSolder
R1, R4: 1k3; R_0603_1608Metric_Pad0.98x0.95mm_HandSolder
R2, R3: 5k1; R_0603_1608Metric_Pad0.98x0.95mm_HandSolder
R5: 22k; R_0603_1608Metric_Pad0.98x0.95mm_HandSolder
R6: 1M; R_0603_1608Metric_Pad0.98x0.95mm_HandSolder
U1: ESP32-S3; XCVR_ESP32S3WROOM1N8R8
U2: USBLC6-2SC6; SOT-23-6_Handsoldering
U3: NCP115ASN330T2G; SOT-23-5_HandSoldering
U4: NRF24L01; QFN-20-1EP_4x4mm_P0.5mm_EP2.5x2.5mm
Y1: Crystal_GND24_Small; Crystal_SMD_2520-4Pin_2.5x2.0mm

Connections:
+3V3: C4.1, C5.1, C6.1, C7.1, C8.1, C10.1, C11.1, C13.1, C14.1, C17.1, C19.1, U1.2 (3V3), U1.3 (EN), U3.5 (out), U4.7 (VDD), U4.15 (VDD), U4.18 (VDD)
+5V: C2.1, C3.1, F1.2, U2.5, U3.1 (in), U3.3 (EN)
ANT1: L1.2, L3.1, U4.12 (ANT1)
ANT2: L1.1, L2.1, U4.13 (ANT2)
CE: U1.24 (IO47), U4.1 (CE)
CSN: U1.23 (IO21), U4.2 (CSN)
GND: C1.2, C2.2, C3.2, C4.2, C5.2, C6.2, C7.2, C8.2, C9.2, C10.2, C11.2, C12.2, C13.2, C14.2, C15.2, C16.2, C17.2, C18.2, C19.2, C21.2, D1.1 (K), D2.1 (K), J1.A1 (GND), J1.A12 (GND), J1.B1 (GND), J1.B12 (GND), J2.2 (Ext), R2.2, R3.2, R5.1, U1.1 (GND), U1.40 (GND), U1.41_1 (GND), U1.41_2 (GND), U1.41_3 (GND), U1.41_4 (GND), U1.41_5 (GND), U1.41_6 (GND), U1.41_7 (GND), U1.41_8 (GND), U1.41_9 (GND), U2.2, U3.2 (GND), U4.8 (VSS), U4.14 (VSS), U4.17 (VSS), U4.20 (VSS), Y1.2, Y1.4
IRQ: U1.19 (IO11), U4.6 (IRQ)
MISO: U1.20 (IO12), U4.5 (MISO)
MOSI: U1.21 (IO13), U4.4 (MOSI)
unnamed: C20.1, L2.2
unnamed: D1.2 (A), R1.2
unnamed: D2.2 (A), R4.2
unnamed: F1.1, J1.A4 (VBUS), J1.A9 (VBUS), J1.B4 (VBUS), J1.B9 (VBUS)
unnamed: J1.A5 (CC1), R3.1
unnamed: J1.B5 (CC2), R2.1
unnamed: C1.1, J1.S1 (SHIELD)
unnamed: C20.2, C21.1, J2.1 (In)
unnamed: R1.1, U1.9 (IO16)
unnamed: R4.1, U1.10 (IO17)
unnamed: C9.1, U4.19 (DVDD)
unnamed: R5.2, U4.16 (IREF)
SCK: U1.22 (IO14), U4.3 (SCK)
USBCON_D+: J1.A6 (D+), J1.B6 (D+), U2.3
USBCON_D-: J1.A7 (D-), J1.B7 (D-), U2.1
USB_D+: U1.14 (IO20), U2.4
USB_D-: U1.13 (IO19), U2.6
VDD_PA: C16.1, C18.1, L3.2, U4.11 (VDD_PA)
XC1: C12.1, R6.1, U4.10 (XC1), Y1.1
XC2: C15.1, R6.2, U4.9 (XC2), Y1.3

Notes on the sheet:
ESP32
fg = 34kHz
USB
NRF24L01

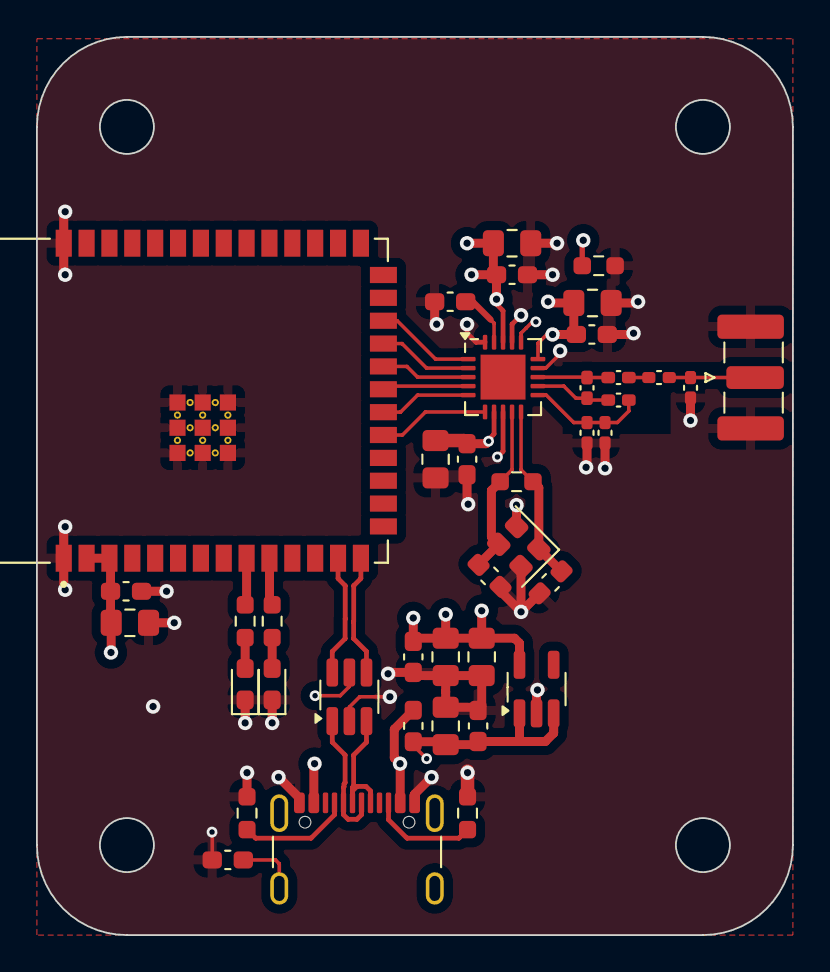
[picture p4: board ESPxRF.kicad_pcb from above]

Board: 4 copper layers, 42.0 x 49.9 mm, 40 parts (0 on the bottom side), 30 nets.

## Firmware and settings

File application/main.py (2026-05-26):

from __future__ import annotations

import asyncio
import json
import sys
import threading
import webbrowser
from contextlib import asynccontextmanager
from pathlib import Path
from typing import Any


APP_DIR = Path(__file__).resolve().parent
REPO_ROOT = APP_DIR.parent
SDK_DIR = REPO_ROOT / "sdk" / "python"
if SDK_DIR.exists() and str(SDK_DIR) not in sys.path:
    sys.path.insert(0, str(SDK_DIR))

try:
    from wireless_dev_bridge import BridgeError, WirelessDevBridge
except ImportError as exc:
    raise SystemExit(
        "Unable to import the Wireless Dev Bridge SDK. Run this app from the "
        "repository checkout or install sdk/python with: python -m pip install -e sdk/python"
    ) from exc

try:
    import serial.tools.list_ports  # type: ignore[import]
except ImportError:
    serial = None  # type: ignore[assignment]

try:
    import uvicorn
    from fastapi import FastAPI, Request
    from fastapi.responses import HTMLResponse, JSONResponse, StreamingResponse
    from fastapi.staticfiles import StaticFiles
except ImportError as exc:
    raise SystemExit(
        "FastAPI and Uvicorn are required. Install with:\n"
        "  pip install -r application/requirements.txt"
    ) from exc

# ── Constants ─────────────────────────────────────────────────────────────────

BAUD_RATE = 115200
DEFAULT_TIMEOUT = 3.0
MAX_PAYLOAD_BYTES = 32
RF_ADDRESS_WIDTH = 5

TRANSPORT_SERIAL = "USB serial"
TRANSPORT_HTTP = "HTTP"
TRANSPORT_WEBSOCKET = "WebSocket"
TRANSPORT_BLE = "BLE"
COMMAND_TRANSPORTS = {TRANSPORT_SERIAL, TRANSPORT_HTTP, TRANSPORT_WEBSOCKET, TRANSPORT_BLE}
EVENT_TRANSPORTS = {TRANSPORT_WEBSOCKET, TRANSPORT_BLE}

HOST = "127.0.0.1"
PORT = 5173

# ── Application state ─────────────────────────────────────────────────────────

_lock = threading.Lock()
_active_bridges: dict[tuple[str, str, float], WirelessDevBridge] = {}
_sse_queues: list[asyncio.Queue] = []
_event_loop: asyncio.AbstractEventLoop | None = None
_event_thread: threading.Thread | None = None
_event_stop: threading.Event | None = None

# ── Validation helpers ────────────────────────────────────────────────────────

def payload_to_hex(value: str, mode: str) -> str:
    if mode == "text":
        data = value.encode("utf-8")
        if not data:
            raise ValueError("Payload must not be empty.")
        if len(data) > MAX_PAYLOAD_BYTES:
            raise ValueError(f"nRF24 payloads are limited to {MAX_PAYLOAD_BYTES} bytes.")
        return data.hex().upper()
    normalized = value.strip()
    if normalized.lower().startswith("0x"):
        normalized = normalized[2:]
    normalized = "".join(normalized.split())
    if not normalized:
        raise ValueError("Payload must not be empty.")
    if len(normalized) % 2:
        raise ValueError("Hex payload must have an even number of characters.")
    try:
        data = bytes.fromhex(normalized)
    except ValueError as exc:
        raise ValueError("Hex payload contains non-hex characters.") from exc
    if len(data) > MAX_PAYLOAD_BYTES:
        raise ValueError(f"nRF24 payloads are limited to {MAX_PAYLOAD_BYTES} bytes.")
    return data.hex().upper()


def validate_address(label: str, value: str, fmt: str) -> None:
    if fmt == "ascii":
        if len(value.encode("ascii", errors="ignore")) != len(value):
            raise ValueError(f"{label} must contain ASCII characters only.")
        if len(value) != RF_ADDRESS_WIDTH:
            raise ValueError(f"{label} must be exactly {RF_ADDRESS_WIDTH} ASCII characters.")
        return
    normalized = value.strip()
    if normalized.lower().startswith("0x"):
        normalized = normalized[2:]
    normalized = "".join(normalized.split())
    if len(normalized) != RF_ADDRESS_WIDTH * 2:
        raise ValueError(f"{label} must be exactly {RF_ADDRESS_WIDTH * 2} hex characters.")
    try:
        bytes.fromhex(normalized)
    except ValueError as exc:
        raise ValueError(f"{label} contains non-hex characters.") from exc


# ── Client pool ───────────────────────────────────────────────────────────────

def _get_client(transport: str, endpoint: str, timeout: float) -> WirelessDevBridge:
    key = (transport, endpoint, timeout)
    with _lock:
        bridge = _active_bridges.get(key)
        if bridge is not None:
            return bridge
        bridge = _make_client(transport, endpoint, timeout)
        _active_bridges[key] = bridge
        return bridge


def _make_client(transport: str, endpoint: str, timeout: float) -> WirelessDevBridge:
    if transport == TRANSPORT_SERIAL:
        return WirelessDevBridge.serial(endpoint, baudrate=BAUD_RATE, timeout=timeout)
    if transport == TRANSPORT_HTTP:
        return WirelessDevBridge.http(endpoint, timeout=timeout)
    if transport == TRANSPORT_WEBSOCKET:
        return WirelessDevBridge.websocket(endpoint, timeout=timeout)
    if transport == TRANSPORT_BLE:
        return WirelessDevBridge.ble(endpoint, timeout=timeout)
    raise ValueError(f"unsupported transport: {transport}")


def _close_client(key: tuple[str, str, float]) -> None:
    with _lock:
        bridge = _active_bridges.pop(key, None)
    if bridge is not None:
        try:
            bridge.close()
        except Exception:
            pass


def _close_all_clients() -> None:
    with _lock:
        keys = list(_active_bridges)
    for key in keys:
        _close_client(key)


# ── SSE broadcast ─────────────────────────────────────────────────────────────

def _broadcast(msg: dict) -> None:
    for q in list(_sse_queues):
        try:
            q.put_nowait(msg)
        except Exception:
            pass


def _push(msg: dict) -> None:
    if _event_loop and not _event_loop.is_closed():
        _event_loop.call_soon_threadsafe(_broadcast, msg)


# ── FastAPI ───────────────────────────────────────────────────────────────────

@asynccontextmanager
async def _lifespan(application: "FastAPI"):
    global _event_loop
    _event_loop = asyncio.get_running_loop()
    try:
        yield
    finally:
        if _event_stop is not None:
            _event_stop.set()
        await asyncio.to_thread(_close_all_clients)
        if _event_thread and _event_thread.is_alive():
            await asyncio.to_thread(_event_thread.join, 2.0)


app = FastAPI(title="Wireless Dev Bridge Workbench", lifespan=_lifespan)
_STATIC = APP_DIR / "static"
app.mount("/static", StaticFiles(directory=str(_STATIC)), name="static")


@app.get("/", response_class=HTMLResponse)
async def root() -> HTMLResponse:
    return HTMLResponse((_STATIC / "index.html").read_text(encoding="utf-8"))


@app.get("/health")
async def health() -> dict:
    return {"ok": True}


@app.get("/api/ports")
async def list_ports() -> dict:
    if serial is None:
        return {"ports": [], "error": "pyserial not installed — install sdk/python with the serial or all extra"}
    ports = [{"device": p.device, "description": p.description} for p in serial.tools.list_ports.comports()]
    return {"ports": ports}


@app.post("/api/command")
async def run_command(body: dict) -> Any:
    transport = body.get("transport", "")
    endpoint = body.get("endpoint", "")
    cmd = body.get("cmd", "")
    params_body = body.get("params") or {}
    if not isinstance(params_body, dict):
        return JSONResponse({"ok": False, "error": "params must be a JSON object"}, status_code=400)
    params: dict = {k: v for k, v in params_body.items() if v is not None}
    try:
        timeout = float(body.get("timeout", DEFAULT_TIMEOUT))
    except (TypeError, ValueError):
        return JSONResponse({"ok": False, "error": "timeout must be a number"}, status_code=400)

    if not transport or not endpoint or not cmd:
        return JSONResponse({"ok": False, "error": "transport, endpoint, and cmd are required"}, status_code=400)
    if transport not in COMMAND_TRANSPORTS:
        return JSONResponse({"ok": False, "error": f"unsupported transport: {transport}"}, status_code=400)

    def _run() -> tuple[dict | None, str | None]:
        try:
            bridge = _get_client(transport, endpoint, timeout)
            return bridge.request(cmd, check=False, **params), None
        except BridgeError as exc:
            _close_client((transport, endpoint, timeout))
            return None, str(exc)
        except Exception as exc:
            _close_client((transport, endpoint, timeout))
            return None, f"{type(exc).__name__}: {exc}"

    response, error = await asyncio.to_thread(_run)
    if error:
        return {"ok": False, "error": error, "cmd": cmd, "data": {}}
    return response


@app.post("/api/disconnect")
async def disconnect() -> dict:
    global _event_stop
    if _event_stop is not None:
        _event_stop.set()
    await asyncio.to_thread(_close_all_clients)
    return {"ok": True}


@app.post("/api/events/start")
async def start_events(body: dict) -> Any:
    global _event_thread, _event_stop
    transport = body.get("transport", TRANSPORT_WEBSOCKET)
    endpoint = body.get("endpoint", "")
    try:
        timeout = float(body.get("timeout", DEFAULT_TIMEOUT))
    except (TypeError, ValueError):
        return JSONResponse({"ok": False, "error": "timeout must be a number"}, status_code=400)
    if transport == TRANSPORT_BLE:
        timeout = max(timeout, 5.0)
    if not endpoint:
        return JSONResponse({"ok": False, "error": "endpoint required"}, status_code=400)
    if transport not in EVENT_TRANSPORTS:
        return JSONResponse({"ok": False, "error": f"unsupported event transport: {transport}"}, status_code=400)
    if _event_thread and _event_thread.is_alive():
        return JSONResponse({"ok": False, "error": "event stream already running"}, status_code=409)
    _event_stop = threading.Event()
    _event_thread = threading.Thread(
        target=_event_worker, args=(transport, endpoint, timeout, _event_stop), daemon=True
    )
    _event_thread.start()
    return {"ok": True}


@app.post("/api/events/stop")
async def stop_events() -> dict:
    if _event_stop is not None:
        _event_stop.set()
    return {"ok": True}


@app.get("/api/events/stream")
async def event_stream(request: Request) -> StreamingResponse:
    q: asyncio.Queue = asyncio.Queue(maxsize=512)
    _sse_queues.append(q)

    async def generate():
        try:
            while True:
                if await request.is_disconnected():
                    break
                try:
                    msg = await asyncio.wait_for(q.get(), timeout=15.0)
                    yield f"data: {json.dumps(msg)}\n\n"
                except asyncio.TimeoutError:
                    yield ": keepalive\n\n"
        finally:
            try:
                _sse_queues.remove(q)
            except ValueError:
                pass

    return StreamingResponse(
        generate(),
        media_type="text/event-stream",
        headers={"Cache-Control": "no-cache", "X-Accel-Buffering": "no"},
    )


# ── Event worker ──────────────────────────────────────────────────────────────

def _event_worker(transport: str, endpoint: str, timeout: float, stop: threading.Event) -> None:
    bridge = None
    try:
        bridge = _make_client(transport, endpoint, timeout)
        _push({"type": "event_state", "status": f"Streaming {transport} {endpoint}"})
        while not stop.is_set():
            try:
                event = bridge.read_event(timeout=1.0)
            except Exception as exc:
                if stop.is_set():
                    break
                low = str(exc).lower()
                if "timeout" in low or "timed out" in low:
                    continue
                _push({"type": "event_error", "message": f"{transport} {endpoint}: {exc}"})
                break
            _push({"type": "event", "data": event})
    except Exception as exc:
        _push({"type": "event_error", "message": f"{transport} {endpoint}: {exc}"})
    finally:
        if bridge is not None:
            try:
                bridge.close()
            except Exception:
                pass
        _push({"type": "event_stopped"})


# ── Entry point ───────────────────────────────────────────────────────────────

def main() -> None:
    def _open_browser():
        import time
        time.sleep(1.2)
        webbrowser.open(f"http://{HOST}:{PORT}")

    threading.Thread(target=_open_browser, daemon=True).start()
    print(f"Wireless Dev Bridge Workbench: http://{HOST}:{PORT}")
    try:
        uvicorn.run(app, host=HOST, port=PORT, log_level="warning")
    finally:
        if _event_stop is not None:
            _event_stop.set()
        _close_all_clients()


if __name__ == "__main__":
    main()

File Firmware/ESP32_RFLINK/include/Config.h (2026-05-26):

#pragma once
#include <Arduino.h>

#ifndef RF_DEFAULT_RX_ADDR
#define RF_DEFAULT_RX_ADDR "NODE1"
#endif

#ifndef RF_DEFAULT_TX_ADDR
#define RF_DEFAULT_TX_ADDR "NODE2"
#endif

#ifndef DEVICE_ROLE
#define DEVICE_ROLE "generic"
#endif

#ifndef WIFI_AP_SSID
#define WIFI_AP_SSID "WirelessDev-Bridge"
#endif

#ifndef WIFI_AP_PASS
#define WIFI_AP_PASS "12345678"
#endif

#ifndef BLE_ENABLED
#define BLE_ENABLED 1
#endif

#ifndef BLE_DEVICE_NAME
#define BLE_DEVICE_NAME "WirelessDev-Bridge"
#endif

#ifndef BUILD_DATE
#define BUILD_DATE __DATE__
#endif

#ifndef BUILD_PROFILE
#define BUILD_PROFILE "dev"
#endif

#ifndef GIT_SHA
#define GIT_SHA ""
#endif

static constexpr uint8_t SETTINGS_SCHEMA_VERSION = 1;

namespace Config {
  // Adjust these GPIOs for the final PCB routing.
  static constexpr uint8_t PIN_NRF_CE   = 45;
  static constexpr uint8_t PIN_NRF_CSN  = 15;
  static constexpr uint8_t PIN_NRF_SCK  = 14;
  static constexpr uint8_t PIN_NRF_MOSI = 13;
  static constexpr uint8_t PIN_NRF_MISO = 12;
  static constexpr uint8_t PIN_NRF_IRQ = 18;
  static constexpr uint8_t PIN_LED_Rx   = 16;
  static constexpr uint8_t PIN_LED_Tx   = 17;
  static constexpr uint8_t PIN_LED      = PIN_LED_Tx;

  static constexpr const char* FW_VERSION = "0.1.0-v1";
  static constexpr const char* PROTOCOL_VERSION = "1.1";
  static constexpr const char* DEVICE_ROLE_NAME = DEVICE_ROLE;
  static constexpr const char* AP_SSID    = WIFI_AP_SSID;
  static constexpr const char* AP_PASS    = WIFI_AP_PASS;
  static constexpr bool BLE_ENABLE = BLE_ENABLED != 0;
  static constexpr const char* BLE_NAME = BLE_DEVICE_NAME;

  static constexpr uint16_t HTTP_PORT = 80;
  static constexpr uint16_t WS_PORT   = 81;

  static constexpr size_t SERIAL_MAX_LINE_LENGTH = 512;
  static constexpr size_t RF_PAYLOAD_MAX = 32;
  static constexpr uint8_t RF_ADDRESS_WIDTH = 5;
  static constexpr uint8_t RF_MAX_PACKETS_PER_POLL = 4;
  static constexpr size_t BLE_MAX_LINE_LENGTH = 512;
  static constexpr size_t BLE_NOTIFY_CHUNK_SIZE = 180;

  static constexpr const char* BLE_SERVICE_UUID = "6e400001-b5a3-f393-e0a9-e50e24dcca9e";
  static constexpr const char* BLE_RX_UUID      = "6e400002-b5a3-f393-e0a9-e50e24dcca9e";
  static constexpr const char* BLE_TX_UUID      = "6e400003-b5a3-f393-e0a9-e50e24dcca9e";

  // nRF24 addresses are fixed-width byte arrays. These defaults are printable
  // for developer usability, but they are still sent as 5 raw address bytes.
  static constexpr uint8_t RF_ADDR_RX[6] = RF_DEFAULT_RX_ADDR;
  static constexpr uint8_t RF_ADDR_TX[6] = RF_DEFAULT_TX_ADDR;
}

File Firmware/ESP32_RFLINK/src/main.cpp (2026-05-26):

#include <Arduino.h>
#include <WiFi.h>
#include <ArduinoJson.h>
#include "Config.h"
#include "Utils.h"
#include "RadioService.h"
#include "SettingsService.h"
#include "BridgeService.h"
#include "BleService.h"
#include "CommandService.h"
#include "WebService.h"
#include "AppState.h"

static void onRfPacket(const uint8_t* data, size_t len) {
  bridgeService.handleRfPacket(data, len);
}

static void emitBootMessage(bool rfOk) {
  JsonDocument doc;
  doc["type"] = "boot";
  doc["ok"] = true;
  doc["cmd"] = "boot";
  JsonObject data = doc["data"].to<JsonObject>();
  data["product"] = "WirelessDevBridge";
  data["fw"] = Config::FW_VERSION;
  data["protocol"] = Config::PROTOCOL_VERSION;
  data["role"] = Config::DEVICE_ROLE_NAME;
  data["uptime_ms"] = millis();
  data["radio_initialized"] = rfOk;
  data["radio_chip_connected"] = radioService.isChipConnected();
  data["ap_ssid"] = settingsService.apSsid();
  data["ap_ip"] = WiFi.softAPIP().toString();
  data["ble_enabled"] = bleService.enabled();
  data["ble_name"] = settingsService.bleName();
  data["settings_loaded"] = settingsService.loadedFromNvs();
  doc["error"] = nullptr;
  sendJsonSerial(doc);
}

void setup() {
  pinMode(Config::PIN_LED, OUTPUT);
  digitalWrite(Config::PIN_LED, LOW);

  Serial.begin(115200);
  delay(500);

  settingsService.begin();
  bool rfOk = radioService.begin();
  radioService.setPacketCallback(onRfPacket);

  bridgeService.begin();
  webService.begin();
  bleService.begin();
  emitBootMessage(rfOk);
  eventLog.add("boot", rfOk ? "ok" : "radio init failed");

  digitalWrite(Config::PIN_LED, HIGH);
}

void loop() {
  commandService.pollSerial();
  radioService.poll();
  webService.poll();
  bleService.poll();

  static uint32_t lastStatus = 0;
  if (millis() - lastStatus > 5000) {
    lastStatus = millis();
    webService.broadcastStatus();
  }
}

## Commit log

2023-08-25 finished nrf schematic
    [ESPxRF.kicad_sch]
2023-08-25 nearly finished V1
    [ESP32-S3-WROOM.step, ESPxRF.kicad_pcb, ESPxRF.kicad_sch]
2023-08-25 ground pour and optimizations
    [ESPxRF.kicad_pcb]
2023-08-25 added side mouting hole for I guess keyrings
    [ESPxRF.kicad_pcb]
2023-08-25 made the ring sturdier and m2
    [ESPxRF.kicad_pcb]
2023-08-25 added pcb size measurements
    [ESPxRF.kicad_pcb]
2023-08-29 added GND plane in two inner layers
    [ESPxRF.kicad_pcb, ESPxRF.kicad_sch]
2023-08-29 added silkscreen name
    [ESPxRF.kicad_pcb]
2023-08-29 went through the DRC and assigned my own kicad libraries
    [ESPxRF.kicad_pcb, ESPxRF.kicad_sch]
2023-08-31 added jlc silkscreen tidied schematic
    [ESPxRF-B_Cu.gbr, ESPxRF-B_Mask.gbr, ESPxRF-B_Paste.gbr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]
2023-09-30 fixed short usb esd protection IC
    [ESPxRF.kicad_pcb]
2023-09-30 fixed usb differential pair
    [ESPxRF.kicad_pcb]
2023-10-02 fixed order number jlc
    [ESPxRF.kicad_pcb]
2023-10-02 added 3d models
    [ESPxRF.kicad_pcb]
2023-10-03 generated gerber
    [ESPxRF-B_Cu.gbr, ESPxRF-B_Mask.gbr, ESPxRF-B_Paste.gbr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]
2023-10-10 removed 0.4mm/0.2mm via from esp32 footprint
    [ESPxRF-B_Cu.gbr, ESPxRF-B_Mask.gbr, ESPxRF-B_Paste.gbr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]
2026-05-05 Organize V1 developer launch package
    [ESP32-S3-WROOM.step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]
2026-05-06 Rev.2 PCB improved layout
    [ESPxRF.kicad_sch]
2026-05-06 added keepout area for antenna and impedance matching network
    [ESPxRF.kicad_pcb]
2026-05-15 Integrate desktop workbench and refresh docs
    [ESPxRF.kicad_pcb]
2026-05-21 Productize Wireless Dev Bridge developer kit
